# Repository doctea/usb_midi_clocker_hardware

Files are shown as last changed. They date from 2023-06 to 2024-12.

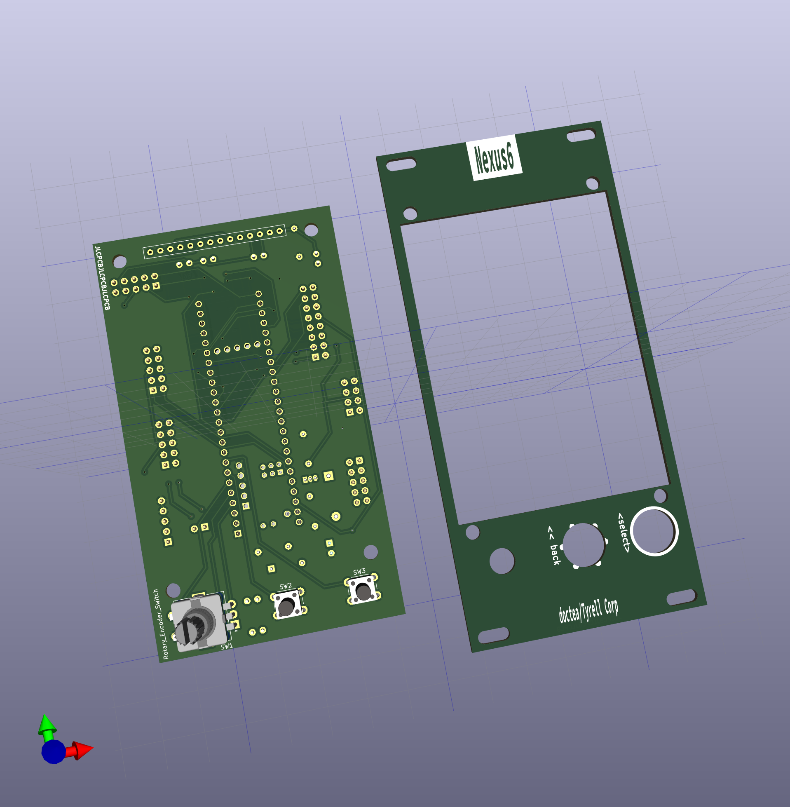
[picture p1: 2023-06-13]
usb_midi_clocker circuits rear.png

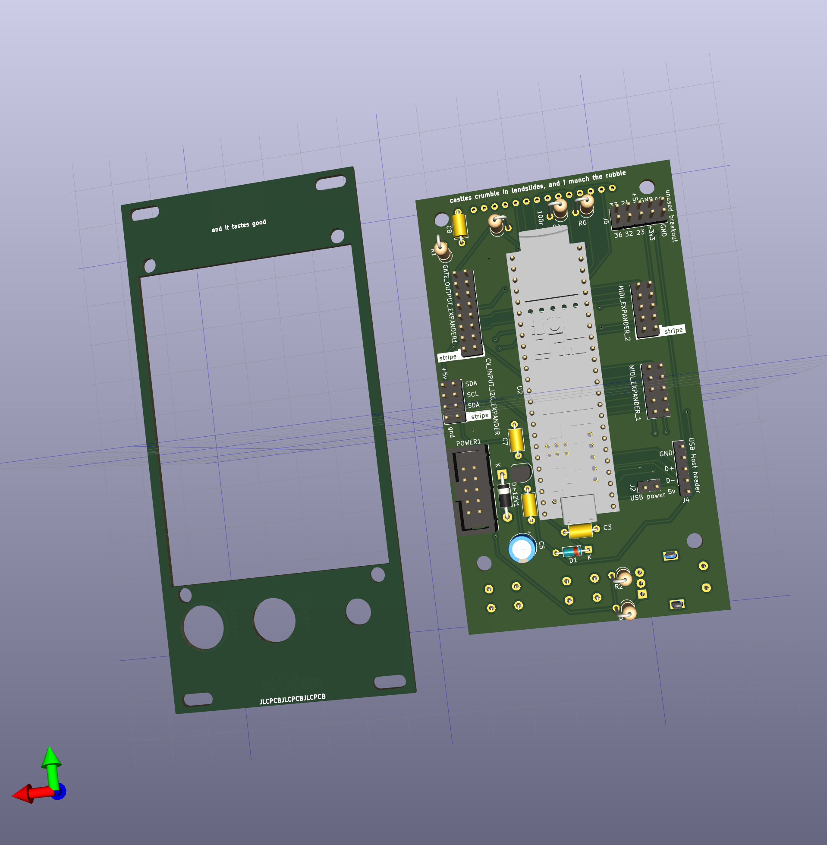
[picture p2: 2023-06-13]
usb_midi_clocker circuits.png

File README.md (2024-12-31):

*IMPORTANT: DO NOT USE THESE FOR ANYTHING YET, THEY ARE VERY MUCH PROTOTYPES AND HAVE SOME PROBLEMS!!!!*

Files for PCB modules for use by [usb_midi_clocker](https://github.com/doctea/usb_midi_clocker/) project.

# Todo

## General

- IMPROVE: reduce size of jack holes to make a snugger fit with less wobble?
- IMPROVE: Some nice panel graphics!

## Main module

### Main module board

- DONE: FIX: Replace the voltage regulator with one that will actually be able to deliver enough amps to power the screen and Teensy *facepalm*
 - ~~Can work around this for the moment by connecting directly to 5v Eurorack power with eg Dupont cables~~
- FIX: Fix/bridge/remove power diode that prevents power from USB going to screen
- IMPROVE: Make the i2c port into a 2x5 connector
- IMPROVE: Add 100ohm resistors on the SPI connectors

### Main module panel

- DONE: IMPROVE: Cutout for display pins in order to allow the panel to sit flat on top of the display without bending like it currently does?
- DONE/UNTESTED: FIX: Make the encoder hole bigger, so that the encoder will fit through

## Gate expander

### Gate expander back board

- FIX: ?? fix whatever the problem is that is making SPI unreliable af and lights randomly seeming to not go off
- DONE/UNTESTED: one of the protection diodes isn't connected to ground
- FIX: eratic behaviour where LEDs stay lit, don't light up properly, etc
	- seems to be fixed/worked around by dropping SPI rate and putting a 22pf cap between MOSI+GND, one between GND+CS1, on between GND+SCK, one between CS1+SCK, and a 100ohm resistor between CS1+SCK too
- FIX: when put into 'inputs' mode, all seem to read HIGH when there isn't anything connected?
- FIX: when put into 'inputs' mode, two of the SEQUENCER channels randomly flicker on/off...?
- FIX: the switch pins currently connect tip to ground; should this go through a large resistor to act as a pull-down?  or not happen at all?
- FIX: layout of the 'sequencer' outputs isn't right, for unknown reasons? (worked around in software)

### Gate expander jacks board

- FIX/UNTESTED: outputs 13+14 had their resistor values accidentally swapped - 1k <-> 47k!

### Gate expander panel

- IMPROVE: make reversible in / out, or label as CLOCK / SEQUENCER

## CV Input expander

### CV Input board

- IMPROVE: make header 2x5 instead of 2x4?

## MIDI expander

- Seems to be working on first attempt!
- IMPROVE: pitch spacing of the resistors/capacitors to allow common components to fit a little better (slightly wider resistor spacing, slightly narrower capacitor spacing)
- IMPROVE: maybe add protection diodes to protect the Teensy's GPIO pins in the event of wrong thing being connected?
- IMPROVE: Make panel double-sided (in+outs 1-4 on one side, 5-6 on the other)
- IMPROVE: probably possible to do this in 3hp instead of 4hp

## USB+SD expander

- TODO: Add a way to directly power USB Host from case's 5V
- TODO: IMPORTANT! Label the USB Host pins so that can tell which end is ground!

## CV Output expander

- DONE: correct the ADC inputs, as they are reversed on the first boards! (A was connected to C and C was connected to A) *facepalm*
- FIX: find correct footprint/component to use for the +12/-12v protection diodes (workaround is to just bridge the connections -- remember to do this BEFORE spending 6 hours debugging everything else!!  Without this, it will look like the DAC chip is working except you won't get any output at all!!!)
- IMPROVE: move the power connector to the inside edge of the board and use right-angle pin headers 
- IMPROVE: use right-angle pin headers/socket for the expander port; maybe get rid of one of the duplicate expander port to give more room for the power connector
- IMPROVE: label the stripe on the expander port(s)

### Addresses

| Address | A1  | A0  | Note |
| --- | --- | --- | ---- |
|  0x4C | LOW | LOW | correct |
|  0x4D | LOW | HIGH | incorrectly seems to stick at 0x4C as if A0 is stuck low? |
|  0x4E | HIGH | LOW | correct |
|  0x4F | HIGH | HIGH | untested - presumed non-working as A0 seems to be stuck low in this hardware revision? |

| Bank | A3 | A2 | Note |
| ---- | -- | -- | ---- |
| 0 | LOW | LOW | Correct |
| 1 | LOW | HIGH | Correct |
| 2 | HIGH | LOW | untested but presumed working |
| 3 | HIGH | HIGH | untested but presumed working |

# Future

- Daughterboards to replace the CV input (currently reliant on Pimoroni 24v ADC module):
 - Own replacement for the Pimoroni board (believe this to be beyond my current ability)
 - Daughterboard to add 3xGate outputs, instead of inputs, based around a GPIO i2c
- Expander-for-the-expander to add switches to select uni-polar/bipolar modes -- with GPIO i2c on there, too, so that we know in software to switch modes and use different calibration data

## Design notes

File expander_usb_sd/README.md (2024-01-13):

#TODO

- DONE check measurements of the USB C screw-holes
- DONE check measurements of cutout for the SD card holder
- DONEish arrange silkscreen text so purpose of each connector is properly usable

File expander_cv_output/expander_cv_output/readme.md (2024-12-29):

https://www.falstad.com/circuit/circuitjs.html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

https://www.falstad.com/circuit/circuitjs.html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

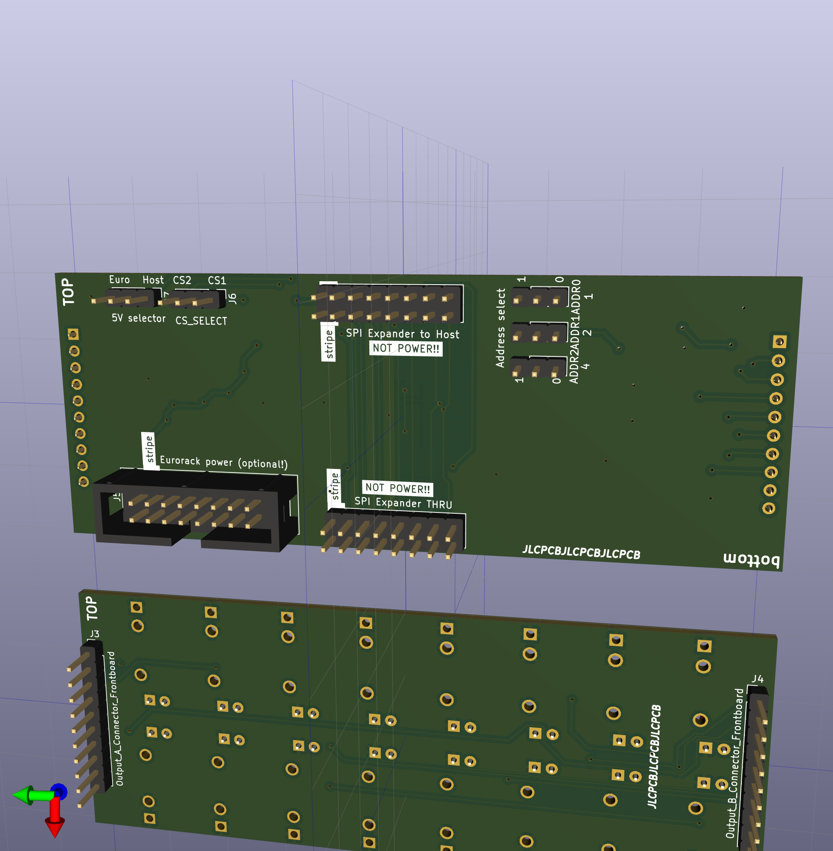
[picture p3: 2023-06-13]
expander_gate_output/expander_gate_output settings.png

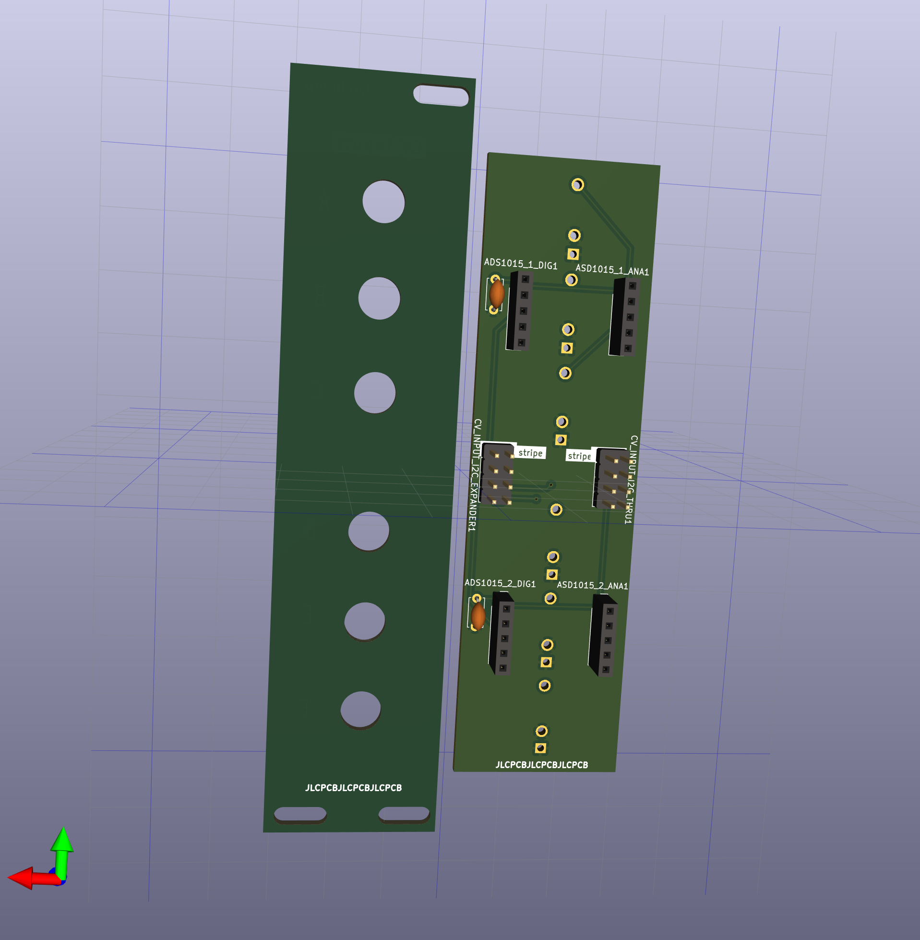
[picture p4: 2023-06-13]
expander_cv_input/expander_cv_input rear.png

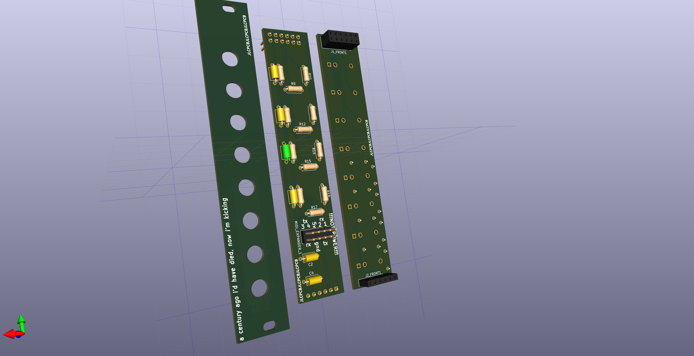
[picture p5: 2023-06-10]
expander_midi/expander_midi.png

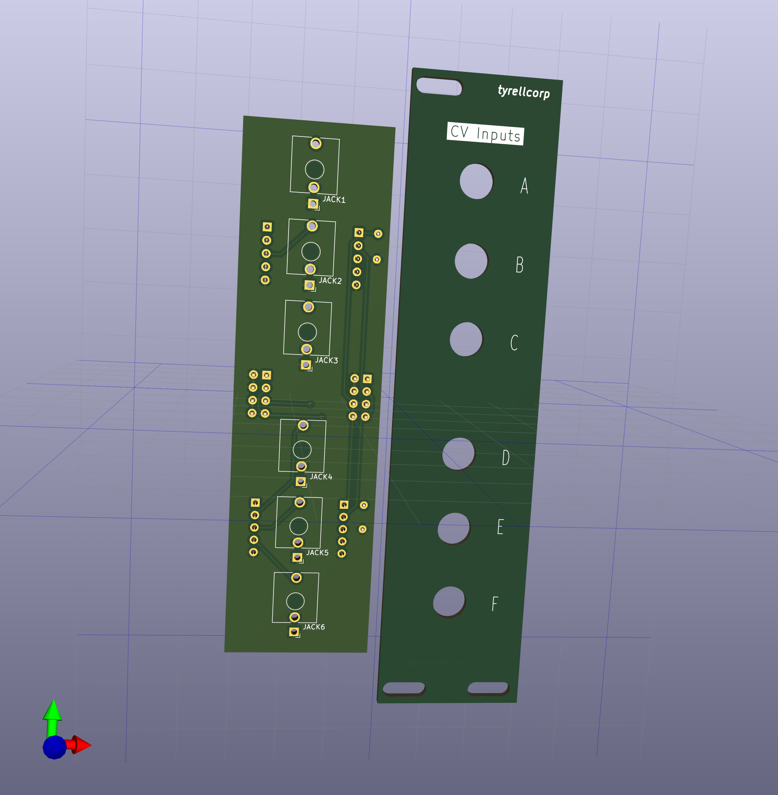
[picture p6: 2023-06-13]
expander_cv_input/expander_cv_input.png

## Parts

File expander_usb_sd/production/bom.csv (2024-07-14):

Designator | Footprint | Quantity | Value | LCSC Part #
External_USB_A_Host1 | ONSHORE_USB-A1VSB6 | 1 | USB_A
H1, H2 | MountingHole_3.2mm_M3 | 2 | MountingHole
J1 | PJS008U-3000-0 | 1 | Micro_SD_Card_Det1
J1-TeensyPower1 | PinHeader_1x02_P2.54mm_Vertical | 1 | USB power - Teensy device
J2 | PinHeader_1x05_P2.54mm_Vertical | 1 | Internal_USB_Host_Teensy
J5-TeensyMicroUSB1 | PinHeader_1x05_P2.54mm_Vertical | 1 | USB 5 pin to Teensy/MicroUSB
J6-USBHost1 | PinHeader_1x05_P2.54mm_Vertical | 1 | USB 5 pin to frontpanel/Type C
SD_connector1 | PinHeader_2x04_P2.54mm_Vertical | 1 | Conn_02x04_Odd_Even
USBHostPower1 | PinHeader_1x02_P2.54mm_Vertical | 1 | USB power - host

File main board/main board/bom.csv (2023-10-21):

Designator | Footprint | Quantity | Value | LCSC Part #
C3, C8 | C_Axial_L5.1mm_D3.1mm_P7.50mm_Horizontal | 2 | C_Small
C5 | CP_Radial_D6.3mm_P2.50mm | 1 | C_Polarized_Small
C6 | C_Axial_L5.1mm_D3.1mm_P7.50mm_Horizontal | 1 | 330nF
C7 | C_Axial_L5.1mm_D3.1mm_P7.50mm_Horizontal | 1 | 100nF
D+12V1 | D_DO-41_SOD81_P10.16mm_Horizontal | 1 | 1N5817
D1 | D_DO-35_SOD27_P7.62mm_Horizontal | 1 | 1N4148
GATE_OUTPUT_EXPANDER1 | PinHeader_2x08_P2.54mm_Vertical | 1 | 16 pin header
I2C_EXPANDER | PinHeader_2x04_P2.54mm_Vertical | 1 | 8 pin header
J2 | PinHeader_1x02_P2.54mm_Vertical | 1 | USB power
J4 | PinHeader_1x05_P2.54mm_Vertical | 1 | USB Host header
J5 | PinHeader_2x05_P2.54mm_Vertical | 1 | Conn_01x09_Pin
MIDI_EXPANDER_1, MIDI_EXPANDER_2 | PinHeader_2x05_P2.54mm_Vertical | 2 | Conn_02x05_Counter_Clockwise
POWER1 | IDC-Header_2x05_P2.54mm_Vertical | 1 | Eurorack power header
R1, R4 | R_Axial_DIN0309_L9.0mm_D3.2mm_P2.54mm_Vertical | 2 | 100R
R2, R3, R5, R6 | R_Axial_DIN0309_L9.0mm_D3.2mm_P2.54mm_Vertical | 4 | R
SW1 | RotaryEncoder_Alps_EC11E-Switch_Vertical_H20mm | 1 | Rotary_Encoder_Switch
SW2 | SW_PUSH_6mm_H13mm | 1 | SW_Push_Back
SW3 | SW_PUSH_6mm_H13mm | 1 | SW_Push_Select
U2 | Teensy41 | 1 | Teensy4.1
U3 | doctea ili9341 3.2 | 1 | TFT_320x240
U4 | TO-220-3_Vertical | 1 | L7805

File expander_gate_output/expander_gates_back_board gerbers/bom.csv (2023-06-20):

Designator | Footprint | Quantity | Value | LCSC Part #
C1, C2, C5, C6, C7 | 0805 | 5 | C_Small
D1, D10, D11, D12, D13, D14, D15, D16, D2, D25, D26, D27, D28, D29, D3, D30, D31, D32, D33, D34, D35, D36, D37, D38, D39, D4, D40, D5, D6, D7, D8, D9 | D_SOD-123 | 32 | BAT43
EXPANDER_THRU, GATE_SPI_OUTPUT_EXPANDER1 | PinHeader_2x08_P2.54mm_Vertical | 2 | 16 pin header
J1 | PinSocket_1x10_P2.54mm_Vertical | 1 | Output_A_Connector_Backboard
J16 | PinHeader_1x03_P2.54mm_Vertical | 1 | ADDR0
J17 | PinHeader_1x03_P2.54mm_Vertical | 1 | ADDR1
J18 | PinHeader_1x03_P2.54mm_Vertical | 1 | ADDR2
J2 | PinSocket_1x10_P2.54mm_Vertical | 1 | Output_B_Connector_Backboard
J5 | IDC-Header_2x08_P2.54mm_Vertical | 1 | Eurorack power
J6 | PinHeader_1x03_P2.54mm_Vertical | 1 | CS_SELECT
J7 | PinHeader_1x03_P2.54mm_Vertical | 1 | 5V selector
U1, U2 | TSSOP-20_4.4x6.5mm_P0.65mm | 2 | TXS0108EPW
U3 | SSOP-28_5.3x10.2mm_P0.65mm | 1 | MCP23S17_SS

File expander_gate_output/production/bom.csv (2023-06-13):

Designator | Footprint | Quantity | Value | LCSC Part #
C1, C2, C5, C6, C7 | 0805 | 5 | C_Small
D1, D10, D11, D12, D13, D14, D15, D16, D2, D25, D26, D27, D28, D29, D3, D30, D31, D32, D33, D34, D35, D36, D37, D38, D39, D4, D40, D5, D6, D7, D8, D9 | 0805 | 32 | BAT43
D17, D18, D19, D20, D21, D22, D23, D24, D41, D42, D43, D44, D45, D46, D47, D48 | LED_D3.0mm | 16 | LED
J1 | PinSocket_1x10_P2.54mm_Vertical | 1 | Output_A_Connector_Backboard
J16 | PinHeader_1x03_P2.54mm_Vertical | 1 | ADDR0
J17 | PinHeader_1x03_P2.54mm_Vertical | 1 | ADDR1
J18 | PinHeader_1x03_P2.54mm_Vertical | 1 | ADDR2
J2 | PinSocket_1x10_P2.54mm_Vertical | 1 | Output_B_Connector_Backboard
J3 | PinHeader_1x10_P2.54mm_Vertical | 1 | Output_A_Connector_Frontboard
J4 | PinHeader_1x10_P2.54mm_Vertical | 1 | Output_B_Connector_Frontboard
J5 | IDC-Header_2x08_P2.54mm_Vertical | 1 | Eurorack power
J6 | PinHeader_1x03_P2.54mm_Vertical | 1 | CS_SELECT
J7 | PinHeader_1x03_P2.54mm_Vertical | 1 | 5V selector
JACK1, JACK14 | Thonkiconn Renumbered | 2 | ~
JACK10, JACK11, JACK12, JACK13, JACK15, JACK16, JACK2, JACK3, JACK4, JACK5, JACK6, JACK7, JACK8, JACK9 | Thonkiconn Renumbered | 14 | fuzzySI_thonkiconn
R1, R11, R13, R15, R17, R19, R21, R23, R25, R27, R29, R3, R31, R5, R7, R9 | 0805 | 16 | 47K
R10, R12, R14, R16, R18, R2, R20, R22, R24, R26, R28, R30, R32, R4, R6, R8 | 0805 | 16 | 1K
SPI Expander THRU | PinHeader_2x08_P2.54mm_Vertical | 1 | NOT POWER!!
SPI Expander to Host | PinHeader_2x08_P2.54mm_Vertical | 1 | 16 pin header
U1, U2 | TSSOP-20_4.4x6.5mm_P0.65mm | 2 | TXS0108EPW
U3 | SSOP-28_5.3x10.2mm_P0.65mm | 1 | MCP23S17_SS

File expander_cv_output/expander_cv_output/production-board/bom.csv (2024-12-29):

Designator | Footprint | Quantity | Value | LCSC Part #
ADDR_A0, ADDR_A1, ADDR_A2, ADDR_A3 | SolderJumper-3_P1.3mm_Open_RoundedPad1.0x1.5mm | 4 | Conn_01x03_Pin
ADS1015_2_DIG1 | PinSocket_1x05_P2.54mm_Vertical | 1 | ADS1015 digital side
ASD1015_2_ANA1 | PinSocket_1x05_P2.54mm_Vertical | 1 | ADS1015 analog side
C1, C12, C13, C16, C17, C18, C19, C2, C5, C6, C7, C9 | 0805 | 12 | 100nF
C10, C11, C14, C15 | 0805 | 4 | 22pF
C3, C4 | CP_Elec_5x5.7 | 2 | C_Polarized_Small
C8 | 0805 | 1 | 10uF
D1 | 0805 | 1 | D
D2 | 0805 | 1 | D_Small
DAC1 | TSSOP-16_4.4x5mm_P0.65mm | 1 | DAC8574IPWG4
EURO_POWER1 | PinHeader_2x08_P2.54mm_Vertical | 1 | Conn_02x08_Odd_Even
J2, J7 | IDC-Header_2x05_P2.54mm_Vertical | 2 | Conn_02x05_Odd_Even
J3 | PinHeader_1x02_P2.54mm_Vertical | 1 | SDA pullup
J4 | PinHeader_1x02_P2.54mm_Vertical | 1 | SCL pullup
J5 | PinHeader_2x08_P2.54mm_Vertical | 1 | Conn_02x08_Counter_Clockwise
JACK_A1, JACK_A2, JACK_B1, JACK_B2, JACK_C1, JACK_C2, JACK_D1 | PJ302M | 7 | PJ302M
LED_A1, LED_B1, LED_C1, LED_D1 | LED_D3.0mm | 4 | LED_Dual_Bidirectional
R1, R5, R6 | 0805 | 3 | 10k
R10, R19, R20, R9 | 0805 | 4 | 2.2k
R11, R12, R21, R22 | 0805 | 4 | 220
R13, R14, R17, R18, R23, R24, R7, R8 | 0805 | 8 | 1K
R15, R16, R25, R26 | 0805 | 4 | 47
R2 | 0805 | 1 | 560
R3, R4 | 0805 | 2 | 150r
U1, U2 | SOIC-14_3.9x8.7mm_P1.27mm | 2 | TL074
U3 | SOT-23_Handsoldering | 1 | LM4040DBZ-5
U4 | SOT-23_Handsoldering | 1 | LD1117S33TR_SOT223
U5 | SOT-23_Handsoldering | 1 | LM4040DBZ-33

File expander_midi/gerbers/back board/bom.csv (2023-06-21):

Designator | Footprint | Quantity | Value | LCSC Part #
C1, C4 | C_Axial_L5.1mm_D3.1mm_P7.50mm_Horizontal | 2 | 100nF
C2, C3, C5, C6 | C_Axial_L5.1mm_D3.1mm_P7.50mm_Horizontal | 4 | 100n
J1_BACK1 | PinHeader_2x06_P2.54mm_Vertical | 1 | Conn_02x06_Odd_Even
J2_BACK1 | PinHeader_1x06_P2.54mm_Vertical | 1 | Conn_01x06_Pin
MIDI_EXPANDER_1 | PinHeader_2x05_P2.54mm_Vertical | 1 | Conn_02x05_Counter_Clockwise
R10, R11, R12, R15, R16, R17, R18, R9 | R_Axial_DIN0207_L6.3mm_D2.5mm_P7.62mm_Horizontal | 8 | 220R
R13, R14, R19, R20 | R_Axial_DIN0207_L6.3mm_D2.5mm_P7.62mm_Horizontal | 4 | 470R
U1 | SOT-223-3_TabPin2 | 1 | LD1117
ULPZWmidi1, ULPZWmidi2, ULPZWmidi3, ULPZWmidi4 | SO-8_3.9x4.9mm_P1.27mm | 4 | HCPL-0631

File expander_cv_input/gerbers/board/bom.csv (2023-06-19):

Designator | Footprint | Quantity | Value | LCSC Part #
ADS1015_1_DIG1, ADS1015_2_DIG1 | PinSocket_1x05_P2.54mm_Vertical | 2 | ADS1015 digital side
ASD1015_1_ANA1, ASD1015_2_ANA1 | PinSocket_1x05_P2.54mm_Vertical | 2 | ADS1015 analog side
C1, C2 | C_Disc_D5.0mm_W2.5mm_P5.00mm | 2 | 100n
CV_INPUT_I2C_EXPANDER1, CV_INPUT_I2C_THRU1 | PinHeader_2x04_P2.54mm_Vertical | 2 | 8 pin header
JACK1, JACK2, JACK3, JACK4, JACK5, JACK6 | Jack_3.5mm_QingPu_WQP-PJ398SM_Vertical_CircularHoles | 6 | AudioJack2_SwitchT

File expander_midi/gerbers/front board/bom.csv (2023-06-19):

Designator | Footprint | Quantity | Value | LCSC Part #
J1_FRONT1 | PinSocket_2x06_P2.54mm_Vertical | 1 | Conn_02x06_Odd_Even
J2_FRONT1 | PinSocket_1x06_P2.54mm_Vertical | 1 | Conn_01x06_Socket
JMIDIIN1, JMIDIIN2, JMIDIIN3, JMIDIIN4, JMIDIOUT1, JMIDIOUT2, JMIDIOUT3, JMIDIOUT4 | Jack_3.5mm_QingPu_WQP-PJ398SM_TRS_Vertical_CircularHoles | 8 | MIDI In Jack 3.5mm stereo jack
R1, R2, R3, R4, R5, R6, R7, R8 | R_Axial_DIN0207_L6.3mm_D2.5mm_P7.62mm_Horizontal | 8 | 47R

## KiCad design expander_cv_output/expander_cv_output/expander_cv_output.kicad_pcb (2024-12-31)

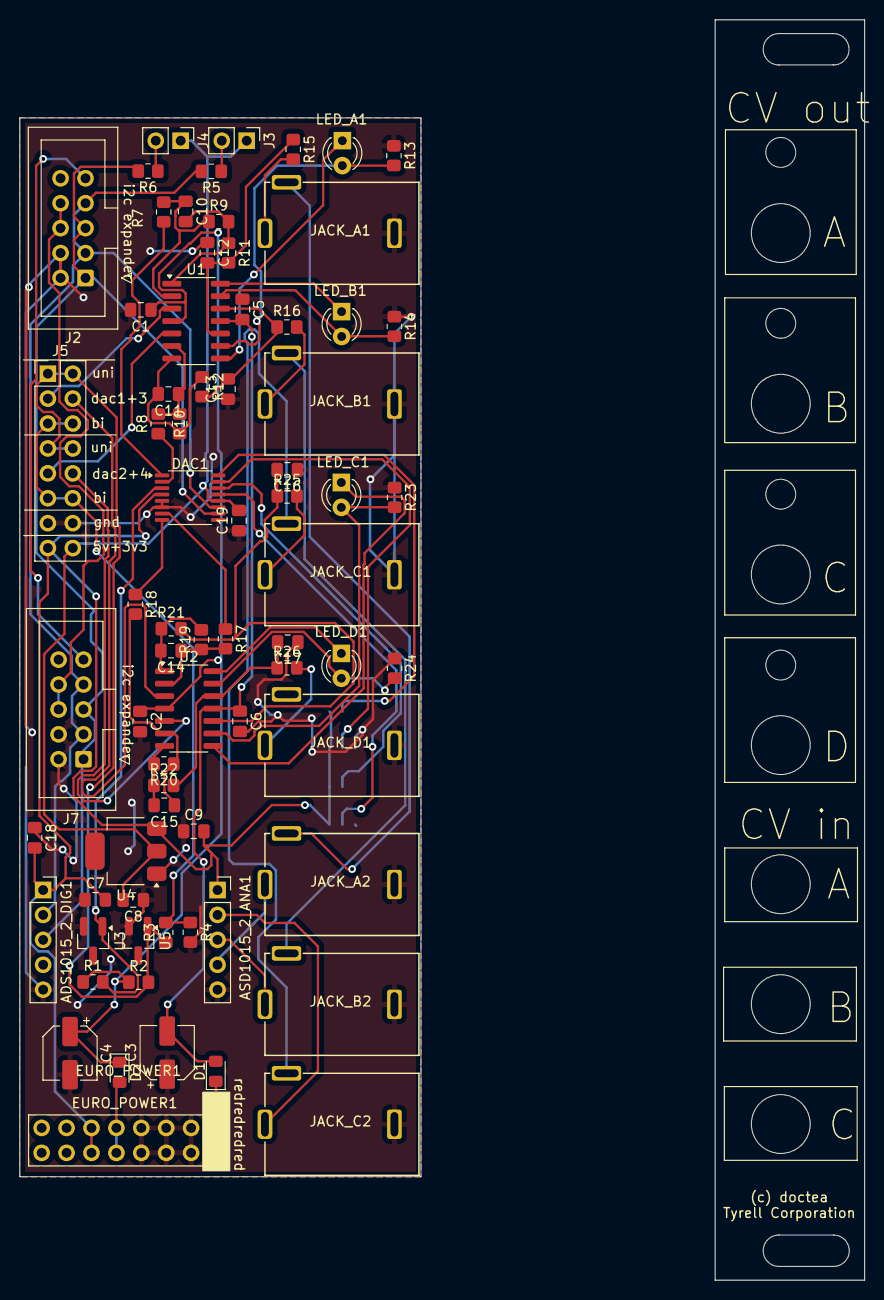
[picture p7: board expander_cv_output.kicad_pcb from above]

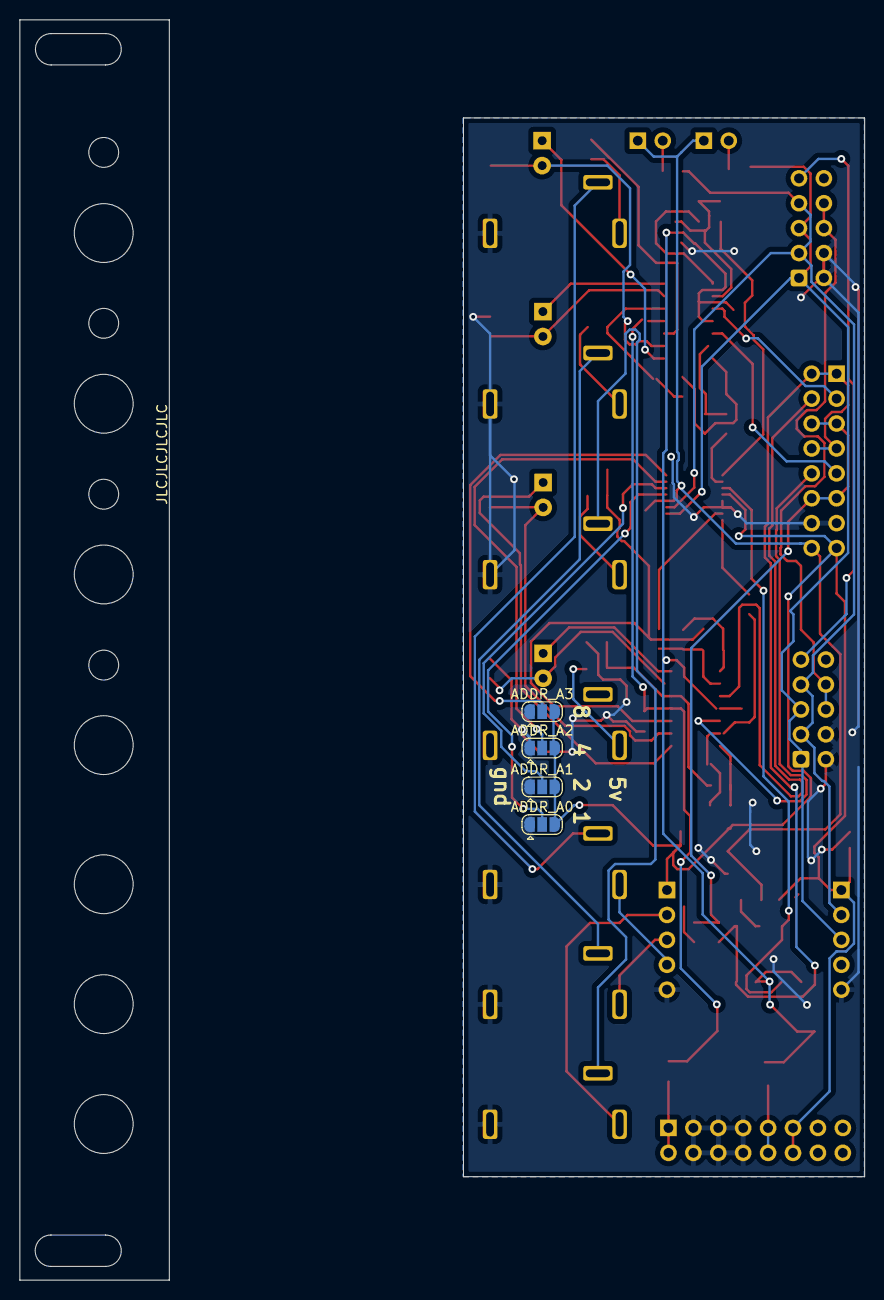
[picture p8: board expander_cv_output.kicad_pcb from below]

Board: 2 copper layers, 40.9 x 108.0 mm, 76 parts (4 on the bottom side), 59 nets.

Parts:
ADDR_A0, ADDR_A1, ADDR_A2, ADDR_A3: Conn_01x03_Pin; SolderJumper-3_P1.3mm_Open_RoundedPad1.0x1.5mm
ADS1015_2_DIG1: ADS1015 digital side; PinSocket_1x05_P2.54mm_Vertical
ASD1015_2_ANA1: ADS1015 analog side; PinSocket_1x05_P2.54mm_Vertical
C1, C2, C5, C6, C7, C9, C12, C13, C16, C17, C18, C19: 100nF; C_0805_2012Metric_Pad1.18x1.45mm_HandSolder
C3, C4: 10uF; CP_Elec_5x5.7
C8: 10uF; C_0805_2012Metric_Pad1.18x1.45mm_HandSolder
C10, C11, C14, C15: 22pF; C_0805_2012Metric_Pad1.18x1.45mm_HandSolder
D1, D2: 1N5817; D_0805_2012Metric_Pad1.15x1.40mm_HandSolder
DAC1: DAC8574IPWG4; TSSOP-16_4.4x5mm_P0.65mm
EURO_POWER1: Conn_02x08_Odd_Even; PinHeader_2x08_P2.54mm_Vertical
J2, J7: Conn_02x05_Odd_Even; IDC-Header_2x05_P2.54mm_Vertical
J3: SDA pullup; PinHeader_1x02_P2.54mm_Vertical
J4: SCL pullup; PinHeader_1x02_P2.54mm_Vertical
J5: Conn_02x08_Counter_Clockwise; PinHeader_2x08_P2.54mm_Vertical
JACK_A1, JACK_A2: PJ302M
JACK_B1, JACK_B2: PJ302M
JACK_C1, JACK_C2: PJ302M
JACK_D1: PJ302M
LED_A1: LED_Dual_Bidirectional; LED_D3.0mm
LED_B1: LED_Dual_Bidirectional; LED_D3.0mm
LED_C1: LED_Dual_Bidirectional; LED_D3.0mm
LED_D1: LED_Dual_Bidirectional; LED_D3.0mm
R1, R5, R6: 10k; R_0805_2012Metric_Pad1.20x1.40mm_HandSolder
R2: 560; R_0805_2012Metric_Pad1.20x1.40mm_HandSolder
R3, R4: 150r; R_0805_2012Metric_Pad1.20x1.40mm_HandSolder
R7, R8, R13, R14, R17, R18, R23, R24: 1K; R_0805_2012Metric_Pad1.20x1.40mm_HandSolder
R9, R10, R19, R20: 2.2k; R_0805_2012Metric_Pad1.20x1.40mm_HandSolder
R11, R12, R21, R22: 220; R_0805_2012Metric_Pad1.20x1.40mm_HandSolder
R15, R16, R25, R26: 47; R_0805_2012Metric_Pad1.20x1.40mm_HandSolder
U1, U2: TL074; SOIC-14_3.9x8.7mm_P1.27mm
U3: LM4040DBZ-5; SOT-23_Handsoldering
U4: LD1117S33TR_SOT223; SOT-223
U5: LM4040DBZ-33; SOT-23_Handsoldering

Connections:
1.65v reference: J5.5, J5.6, J5.11, J5.12, R3.2, R4.1
3.3V: C8.2, C19.2, DAC1.12 (IOVDD), J3.1, J4.1, J5.16, U4.2 (VO)
3.3v reference: J5.1, J5.2, J5.7, J5.8, R2.2, R3.1, U5.1 (K)
5V: ADDR_A0.3, ADDR_A1.3, ADDR_A2.3, ADDR_A3.3, ADS1015_2_DIG1.1, ASD1015_2_ANA1.1, C7.2, C9.2, C18.2, DAC1.4 (VDD), EURO_POWER1.11, EURO_POWER1.12, J5.15, U4.3 (VI)
5v reference: DAC1.3 (VREFH), R1.2, U3.1 (K)
12V: C1.1, C2.1, C4.1, D2.1 (K), R1.1, R2.1, U1.4 (V+), U2.4 (V+)
+5V from Host: J2.6, J2.8, J7.6, J7.8
-12V: C3.2, C5.2, C6.1, D1.2 (A), U1.11 (V-), U2.11 (V-)
CV GND: ADDR_A0.1, ADDR_A1.1, ADDR_A2.1, ADDR_A3.1, ADS1015_2_DIG1.5, ASD1015_2_ANA1.5, C1.2, C2.2, C3.1, C4.2, C5.1, C6.2, C7.1, C8.1, C9.1, C12.1, C13.1, C16.1, C17.1, C18.1, C19.1, DAC1.5 (VREFL), DAC1.6 (GND), DAC1.9 (LDAC), EURO_POWER1.3, EURO_POWER1.4, EURO_POWER1.5, EURO_POWER1.6, EURO_POWER1.7, EURO_POWER1.8, J2.2, J2.4, J5.13, J5.14, J7.2, J7.4, JACK_A1.1, JACK_A2.1, JACK_B1.1, JACK_B2.1, JACK_C1.1, JACK_C2.1, JACK_D1.1, R4.2, R13.1, R14.1, R23.1, R24.1, U3.2 (A), U4.1 (GND), U5.2 (A)
DAC 1 Bias: J5.3, U1.3 (+)
DAC 2 Bias: J5.9, U1.5 (+)
DAC 3 Bias: J5.4, U2.3 (+)
DAC 4 Bias: J5.10, U2.5 (+)
DAC output 1: DAC1.1 (VOUTA), R7.1
DAC output 2: DAC1.2 (VOUTB), R8.1
DAC output 3: DAC1.7 (VOUTC), R17.1
DAC output 4: DAC1.8 (VOUTD), R18.1
Input Frontboard A: ASD1015_2_ANA1.4, JACK_A2.3
Input Frontboard B: ASD1015_2_ANA1.3, JACK_B2.3
Input Frontboard C: ASD1015_2_ANA1.2, JACK_C2.3
unnamed: ADDR_A0.2, DAC1.13 (A0)
unnamed: ADDR_A1.2, DAC1.14 (A1)
unnamed: ADDR_A2.2, DAC1.15 (A2)
unnamed: ADDR_A3.2, DAC1.16 (A3)
unnamed: C10.2, R9.2, R11.1, U1.1
unnamed: C11.2, R10.2, R12.1, U1.7
unnamed: C14.2, R19.2, R21.1, U2.1
unnamed: C15.2, R20.2, R22.1, U2.7
unnamed: D1.1 (K), EURO_POWER1.1, EURO_POWER1.2
unnamed: D2.2 (A), EURO_POWER1.9, EURO_POWER1.10
unnamed: J2.9, J7.9
unnamed: J2.10, J7.10
unnamed: J3.2, R5.1
unnamed: J4.2, R6.1
unnamed: C10.1, R7.2, R9.1, U1.2 (-)
unnamed: C11.1, R8.2, R10.1, U1.6 (-)
unnamed: C12.2, R11.2, R15.1, U1.10 (+)
unnamed: C13.2, R12.2, R16.1, U1.12 (+)
unnamed: C14.1, R17.2, R19.1, U2.2 (-)
unnamed: C15.1, R18.2, R20.1, U2.6 (-)
unnamed: C16.2, R21.2, R25.1, U2.10 (+)
unnamed: C17.2, R22.2, R26.1, U2.12 (+)
Normal A: JACK_A1.2, JACK_A2.2
Normal B: JACK_B1.2, JACK_B2.2
Normal C: JACK_C1.2, JACK_C2.2
Out A LED Backboard: LED_A1.1 (KA), U1.8
Out A LED Return Backboard: LED_A1.2 (AK), R13.2, U1.9 (-)
Out B LED Backboard: LED_B1.1 (KA), U1.14
Out B LED Return Backboard: LED_B1.2 (AK), R14.2, U1.13 (-)
Out C LED Backboard: LED_C1.1 (KA), U2.8
Out C LED Return Backboard: LED_C1.2 (AK), R23.2, U2.9 (-)
Out D LED Backboard: LED_D1.1 (KA), U2.14
Out D LED Return Backboard: LED_D1.2 (AK), R24.2, U2.13 (-)
Output Backboard A: JACK_A1.3, R15.2
Output Backboard B: JACK_B1.3, R16.2
Output Backboard C: JACK_C1.3, R25.2
Output Backboard D: JACK_D1.3, R26.2
i2c SCL: ADS1015_2_DIG1.3, DAC1.10 (SCL), J2.1, J2.5, J7.1, J7.5, R6.2
i2c SDA: ADS1015_2_DIG1.2, DAC1.11 (SDA), J2.3, J2.7, J7.3, J7.7, R5.2

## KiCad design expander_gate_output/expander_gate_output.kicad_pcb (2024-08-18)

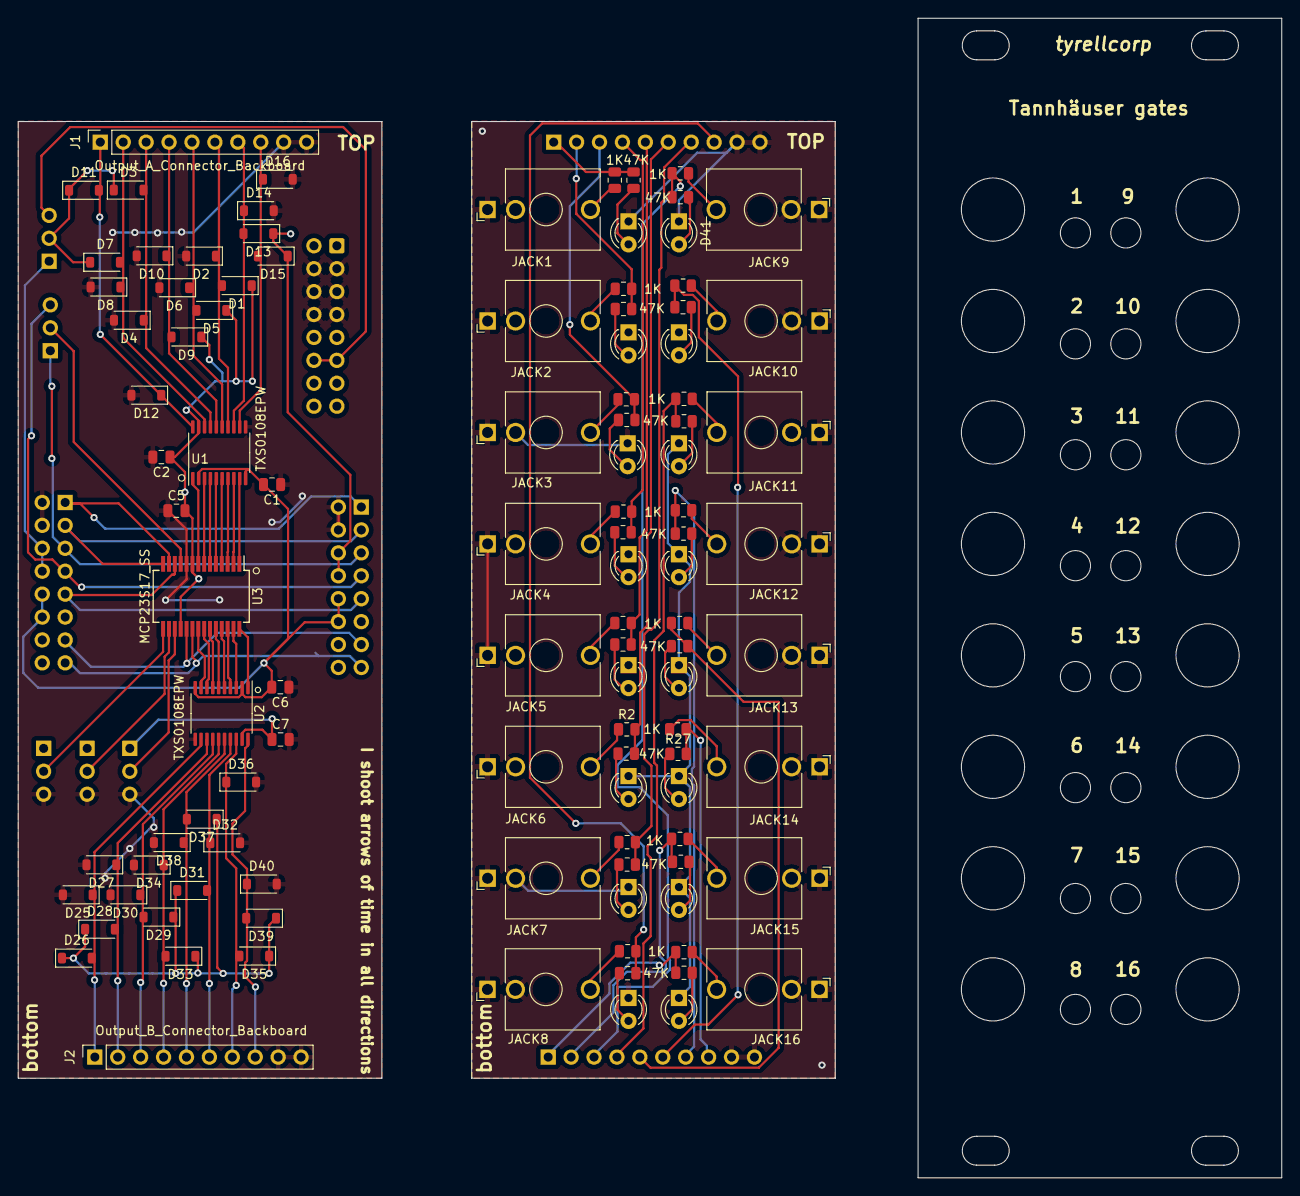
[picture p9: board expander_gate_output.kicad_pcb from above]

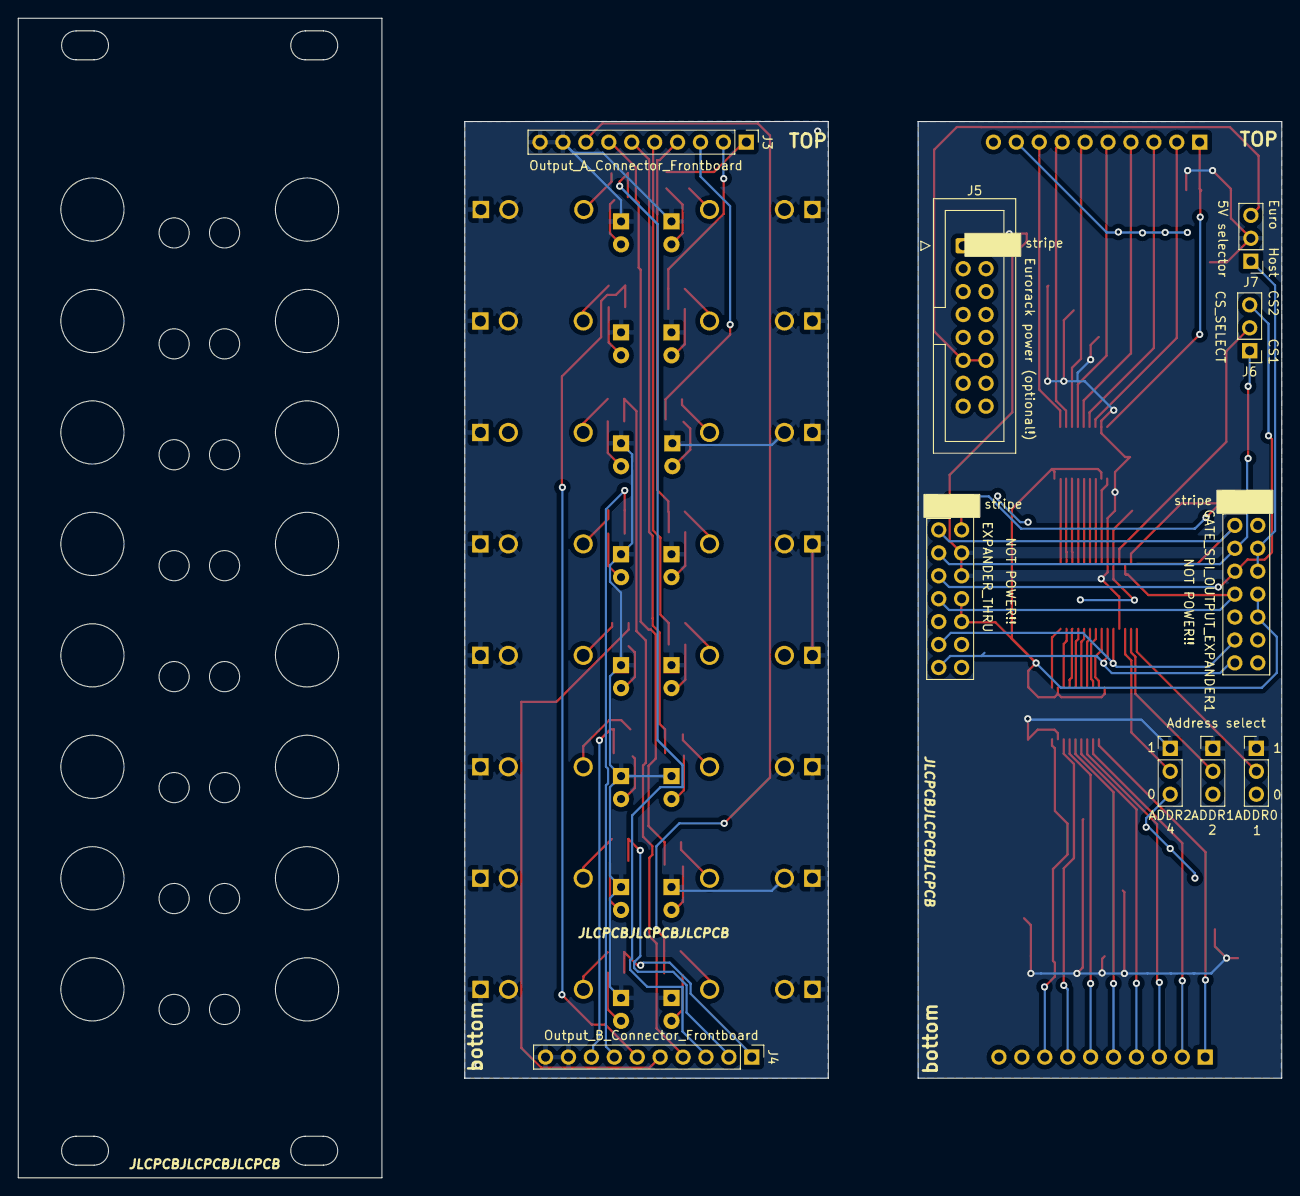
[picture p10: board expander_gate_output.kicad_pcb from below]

Board: 2 copper layers, 140.0 x 128.5 mm, 116 parts (10 on the bottom side), 96 nets.

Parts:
C1, C2, C5, C6, C7: C_Small; C_0805_2012Metric
D1, D2, D3, D4, D5, D6, D7, D8, D9, D10, D11, D12, D13, D14, D15, D16, D25, D26, D27, D28, D29, D30, D31, D32, D33, D34, D35, D36, D37, D38, D39, D40: BAT43; D_SOD-123
D17, D18, D19, D20, D21, D22, D23, D24, D41, D42, D43, D44, D45, D46, D47, D48: LED; LED_D3.0mm
EXPANDER_THRU: 16 pin header; PinHeader_2x08_P2.54mm_Vertical
GATE_SPI_OUTPUT_EXPANDER1: 16 pin header; PinHeader_2x08_P2.54mm_Vertical
J1: Output_A_Connector_Backboard; PinSocket_1x10_P2.54mm_Vertical
J2: Output_B_Connector_Backboard; PinSocket_1x10_P2.54mm_Vertical
J3: Output_A_Connector_Frontboard; PinHeader_1x10_P2.54mm_Vertical
J4: Output_B_Connector_Frontboard; PinHeader_1x10_P2.54mm_Vertical
J5: Eurorack power; IDC-Header_2x08_P2.54mm_Vertical
J6: CS_SELECT; PinHeader_1x03_P2.54mm_Vertical
J7: 5V selector; PinHeader_1x03_P2.54mm_Vertical
J16: ADDR0; PinHeader_1x03_P2.54mm_Vertical
J17: ADDR1; PinHeader_1x03_P2.54mm_Vertical
J18: ADDR2; PinHeader_1x03_P2.54mm_Vertical
JACK1, JACK14: Thonkiconn Renumbered
JACK2, JACK3, JACK4, JACK5, JACK6, JACK7, JACK8, JACK9, JACK10, JACK11, JACK12, JACK13, JACK15, JACK16: fuzzySI_thonkiconn; Thonkiconn Renumbered
R1, R3, R5, R7, R9, R11, R13, R15, R17, R19, R21, R23, R25, R27, R29, R31: 47K; R_0805_2012Metric
R2, R4, R6, R8, R10, R12, R14, R16, R18, R20, R22, R24, R26, R28, R30, R32: 1K; R_0805_2012Metric
U1, U2: TXS0108EPW; TSSOP-20_4.4x6.5mm_P0.65mm
U3: MCP23S17_SS; SSOP-28_5.3x10.2mm_P0.65mm

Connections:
+3V3: C1.2, C6.2, EXPANDER_THRU.10, EXPANDER_THRU.12, GATE_SPI_OUTPUT_EXPANDER1.10, GATE_SPI_OUTPUT_EXPANDER1.12, U1.2 (VCCA), U1.10 (OE), U2.2 (VCCA), U2.10 (OE)
+5V: C2.1, C5.2, C7.1, D1.1 (K), D3.1 (K), D5.1 (K), D7.1 (K), D9.1 (K), D11.1 (K), D13.1 (K), D15.1 (K), D26.1 (K), D28.1 (K), D29.1 (K), D31.1 (K), D33.1 (K), D35.1 (K), D37.1 (K), D39.1 (K), EXPANDER_THRU.6, EXPANDER_THRU.8, J7.2, J16.1, J17.1, J18.1, U1.19 (VCCB), U2.19 (VCCB), U3.9 (VDD), U3.18 (~RESET)
+5V from Eurorack: J5.11, J5.12, J7.3
+5V from main: GATE_SPI_OUTPUT_EXPANDER1.6, GATE_SPI_OUTPUT_EXPANDER1.8, J7.1
A0: J16.2, U3.15 (A0)
A1: J17.2, U3.16 (A1)
A2: J18.2, U3.17 (A2)
CS_1: EXPANDER_THRU.5, GATE_SPI_OUTPUT_EXPANDER1.5, J6.1
CS_2: EXPANDER_THRU.7, GATE_SPI_OUTPUT_EXPANDER1.7, J6.3
CS_INPUT: J6.2, U3.11 (~CS)
GATE_1: U1.9 (A8), U3.1 (GPB0)
GATE_2: U1.8 (A7), U3.2 (GPB1)
GATE_3: U1.7 (A6), U3.3 (GPB2)
GATE_4: U1.6 (A5), U3.4 (GPB3)
GATE_5: U1.5 (A4), U3.5 (GPB4)
GATE_6: U1.4 (A3), U3.6 (GPB5)
GATE_7: U1.3 (A2), U3.7 (GPB6)
GATE_8: U1.1 (A1), U3.8 (GPB7)
GATE_9: U2.9 (A8), U3.21 (GPA0)
GATE_10: U2.8 (A7), U3.22 (GPA1)
GATE_11: U2.7 (A6), U3.23 (GPA2)
GATE_12: U2.6 (A5), U3.24 (GPA3)
GATE_13: U2.5 (A4), U3.25 (GPA4)
GATE_14: U2.4 (A3), U3.26 (GPA5)
GATE_15: U2.3 (A2), U3.27 (GPA6)
GATE_16: U2.1 (A1), U3.28 (GPA7)
GND: C1.1, C2.2, C5.1, C6.1, C7.2, D2.2 (A), D4.2 (A), D6.2 (A), D8.2 (A), D10.2 (A), D12.2 (A), D14.2 (A), D16.2 (A), D17.1 (K), D18.1 (K), D19.1 (K), D20.1 (K), D21.1 (K), D22.1 (K), D23.1 (K), D24.1 (K), D25.2 (A), D27.2 (A), D30.2 (A), D32.2 (A), D34.2 (A), D36.2 (A), D38.2 (A), D40.2 (A), D41.1 (K), D42.1 (K), D43.1 (K), D44.1 (K), D45.1 (K), D46.1 (K), D47.1 (K), D48.1 (K), EXPANDER_THRU.2, EXPANDER_THRU.4, GATE_SPI_OUTPUT_EXPANDER1.2, GATE_SPI_OUTPUT_EXPANDER1.4, J1.9, J1.10, J2.9, J2.10, J3.9, J3.10, J4.9, J4.10, J5.3, J5.4, J5.5, J5.6, J5.7, J5.8, J16.3, J17.3, J18.3, JACK1.1, JACK1.2, JACK2.1, JACK2.2, JACK3.1, JACK3.2, JACK4.1, JACK4.2, JACK5.1, JACK6.1, JACK6.2, JACK7.1, JACK7.2, JACK8.1, JACK8.2, JACK9.1, JACK9.2, JACK10.1, JACK10.2, JACK11.1, JACK12.1, JACK12.2, JACK13.1, JACK13.2, JACK14.1, JACK14.2, JACK15.1, JACK15.2, JACK16.1, JACK16.2, U1.11 (GND), U2.11 (GND), U3.10 (VSS)
INT_1: EXPANDER_THRU.15, GATE_SPI_OUTPUT_EXPANDER1.15, U3.20 (INTA)
INT_2: EXPANDER_THRU.13, GATE_SPI_OUTPUT_EXPANDER1.13, U3.19 (INTB)
MISO: EXPANDER_THRU.3, GATE_SPI_OUTPUT_EXPANDER1.3, U3.14 (SO)
MOSI: EXPANDER_THRU.1, GATE_SPI_OUTPUT_EXPANDER1.1, U3.13 (SI)
unnamed: D17.2 (A), R1.1
unnamed: D18.2 (A), R3.1
unnamed: D19.2 (A), R5.1
unnamed: D20.2 (A), R7.1
unnamed: D21.2 (A), R9.1
unnamed: D22.2 (A), R11.1
unnamed: D23.2 (A), R13.1
unnamed: D24.2 (A), R15.1
unnamed: D41.2 (A), R17.1
unnamed: D42.2 (A), R19.1
unnamed: D43.2 (A), R21.1
unnamed: D44.2 (A), R23.1
unnamed: D45.2 (A), R25.1
unnamed: D46.2 (A), R27.1
unnamed: D47.2 (A), R29.1
unnamed: D48.2 (A), R31.1
unnamed: JACK1.3, R12.1
unnamed: JACK2.3, R8.1
unnamed: JACK3.3, R4.1
unnamed: JACK4.3, R10.1
unnamed: JACK5.3, R6.1
unnamed: JACK6.3, R2.1
unnamed: JACK7.3, R14.1
unnamed: JACK8.3, R16.1
unnamed: JACK9.3, R18.1
unnamed: JACK10.3, R20.1
unnamed: JACK11.3, R22.1
unnamed: JACK12.3, R24.1
unnamed: JACK13.3, R26.1
unnamed: JACK14.3, R28.1
unnamed: JACK15.3, R30.1
unnamed: JACK16.3, R32.1
SCK: EXPANDER_THRU.9, GATE_SPI_OUTPUT_EXPANDER1.9, U3.12 (SCK)
output_1_backboard: D11.2 (A), D12.1 (K), J1.1, U1.20 (B1)
output_1_frontboard: J3.1, R11.2, R12.2
output_2_backboard: D7.2 (A), D8.1 (K), J1.2, U1.18 (B2)
output_2_frontboard: J3.2, R7.2, R8.2
output_3_backboard: D3.2 (A), D4.1 (K), J1.3, U1.17 (B3)
output_3_frontboard: J3.3, R3.2, R4.2
output_4_backboard: D9.2 (A), D10.1 (K), J1.4, U1.16 (B4)
output_4_frontboard: J3.4, R9.2, R10.2
output_5_backboard: D5.2 (A), D6.1 (K), J1.5, U1.15 (B5)
output_5_frontboard: J3.5, R5.2, R6.2
output_6_backboard: D1.2 (A), D2.1 (K), J1.6, U1.14 (B6)
output_6_frontboard: J3.6, R1.2, R2.2
output_7_backboard: D13.2 (A), D14.1 (K), J1.7, U1.13 (B7)
output_7_frontboard: J3.7, R13.2, R14.2
output_8_backboard: D15.2 (A), D16.1 (K), J1.8, U1.12 (B8)
output_8_frontboard: J3.8, R15.2, R16.2
output_9_backboard: D39.2 (A), D40.1 (K), J2.8, U2.20 (B1)
output_9_frontboard: J4.8, R27.2, R28.2
output_10_backboard: D35.2 (A), D36.1 (K), J2.7, U2.18 (B2)
output_10_frontboard: J4.7, R23.2, R24.2
output_11_backboard: D31.2 (A), D32.1 (K), J2.6, U2.17 (B3)
output_11_frontboard: J4.6, R19.2, R20.2
output_12_backboard: D37.2 (A), D38.1 (K), J2.5, U2.16 (B4)
output_12_frontboard: J4.5, R25.2, R26.2
output_13_backboard: D33.2 (A), D34.1 (K), J2.4, U2.15 (B5)
output_13_frontboard: J4.4, R21.2, R22.2
output_14_backboard: D29.2 (A), D30.1 (K), J2.3, U2.14 (B6)
output_14_frontboard: J4.3, R17.2, R18.2
output_15_backboard: D27.1 (K), D28.2 (A), J2.2, U2.13 (B7)
output_15_frontboard: J4.2, R29.2, R30.2
output_16_backboard: D25.1 (K), D26.2 (A), J2.1, U2.12 (B8)
output_16_frontboard: J4.1, R31.2, R32.2

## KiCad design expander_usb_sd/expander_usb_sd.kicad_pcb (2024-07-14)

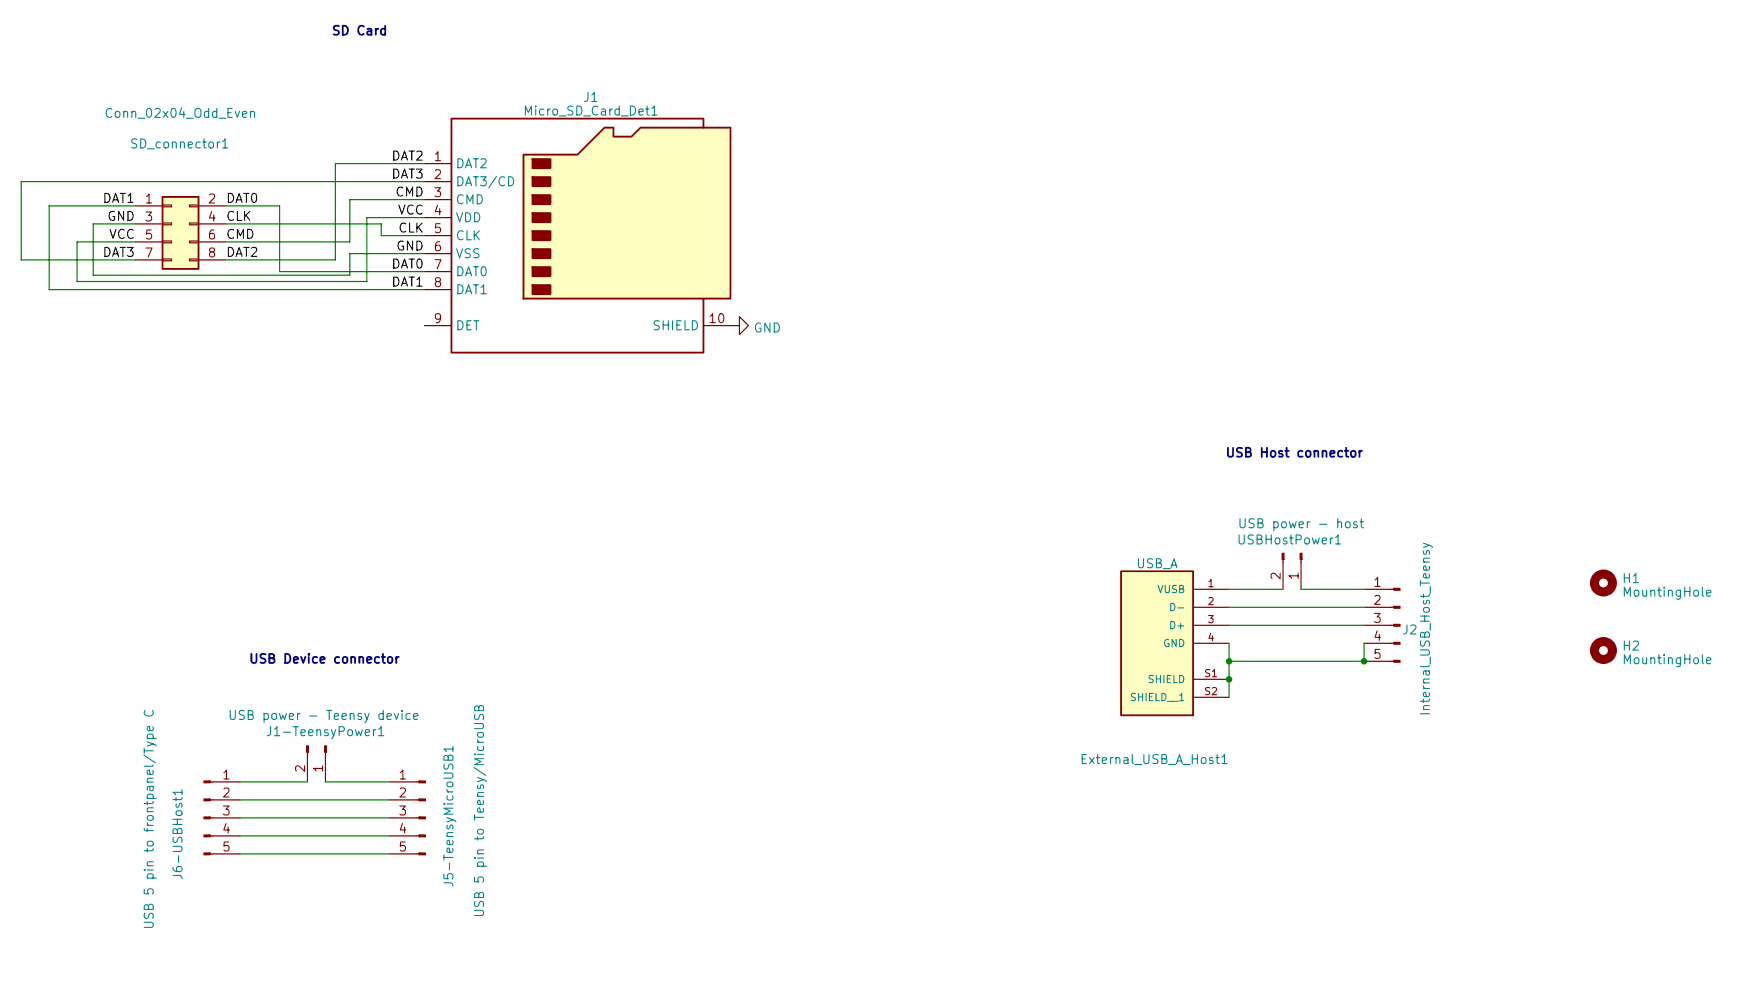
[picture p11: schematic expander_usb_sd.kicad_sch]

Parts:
External_USB_A_Host1: USB_A; ONSHORE_USB-A1VSB6; PARTREV D
H1, H2: MountingHole; MountingHole_3.2mm_M3
J1: Micro_SD_Card_Det1; PJS008U-3000-0
J1-TeensyPower1: USB power - Teensy device; PinHeader_1x02_P2.54mm_Vertical
J2: Internal_USB_Host_Teensy; PinHeader_1x05_P2.54mm_Vertical
J5-TeensyMicroUSB1: USB 5 pin to Teensy/MicroUSB; PinHeader_1x05_P2.54mm_Vertical
J6-USBHost1: USB 5 pin to frontpanel/Type C; PinHeader_1x05_P2.54mm_Vertical
SD_connector1: Conn_02x04_Odd_Even; PinHeader_2x04_P2.54mm_Vertical
USBHostPower1: USB power - host; PinHeader_1x02_P2.54mm_Vertical

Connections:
/CLK: J1.5 (CLK), SD_connector1.4
/CMD: J1.3 (CMD), SD_connector1.6
/DAT0: J1.7 (DAT0), SD_connector1.2
/DAT1: J1.8 (DAT1), SD_connector1.1
/DAT2: J1.1 (DAT2), SD_connector1.8
/DAT3: J1.2 (DAT3/CD), SD_connector1.7
/VCC: J1.4 (VDD), SD_connector1.5
GND: J1.6 (VSS), J1.10 (SHIELD), SD_connector1.3
unnamed: External_USB_A_Host1.3 (D+), J2.3
unnamed: External_USB_A_Host1.2 (D-), J2.2
unnamed: External_USB_A_Host1.4 (GND), External_USB_A_Host1.S1 (SHIELD), External_USB_A_Host1.S2 (SHIELD__1), J2.4, J2.5
unnamed: External_USB_A_Host1.1 (VBUS), USBHostPower1.2
unnamed: J1-TeensyPower1.1, J5-TeensyMicroUSB1.1
unnamed: J1-TeensyPower1.2, J6-USBHost1.1
unnamed: J2.1, USBHostPower1.1
unnamed: J5-TeensyMicroUSB1.2, J6-USBHost1.2
unnamed: J5-TeensyMicroUSB1.3, J6-USBHost1.3
unnamed: J5-TeensyMicroUSB1.4, J6-USBHost1.4
unnamed: J5-TeensyMicroUSB1.5, J6-USBHost1.5

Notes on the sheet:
USB Host connector
SD Card
USB Device connector

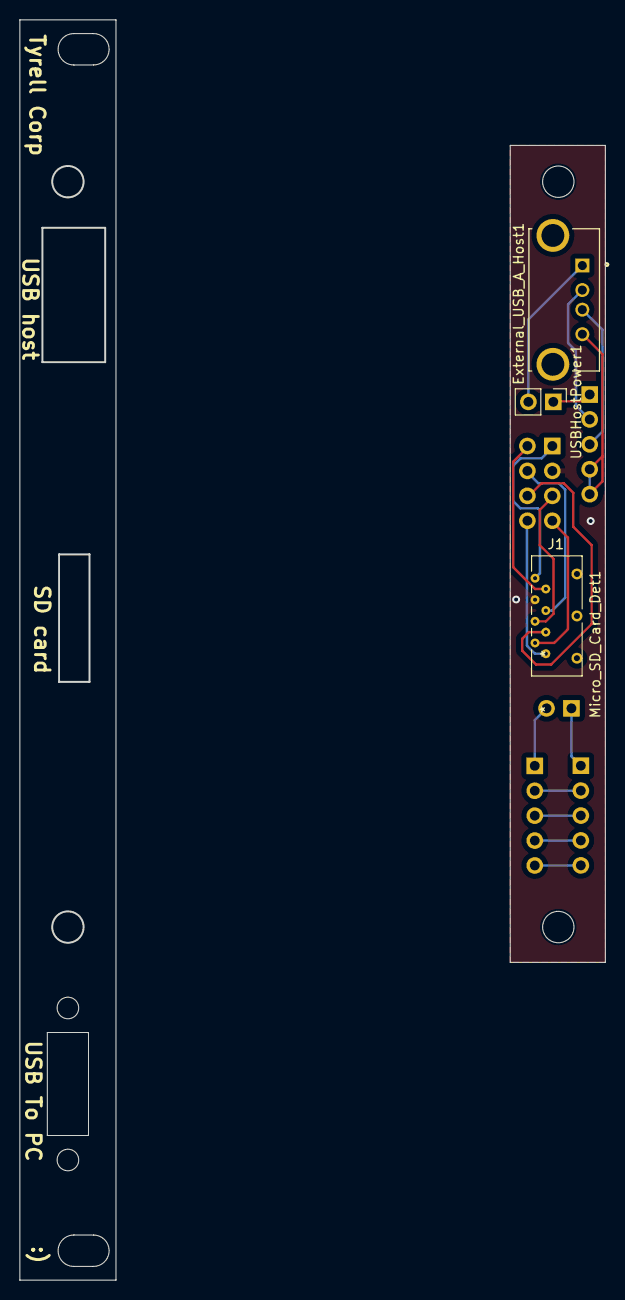
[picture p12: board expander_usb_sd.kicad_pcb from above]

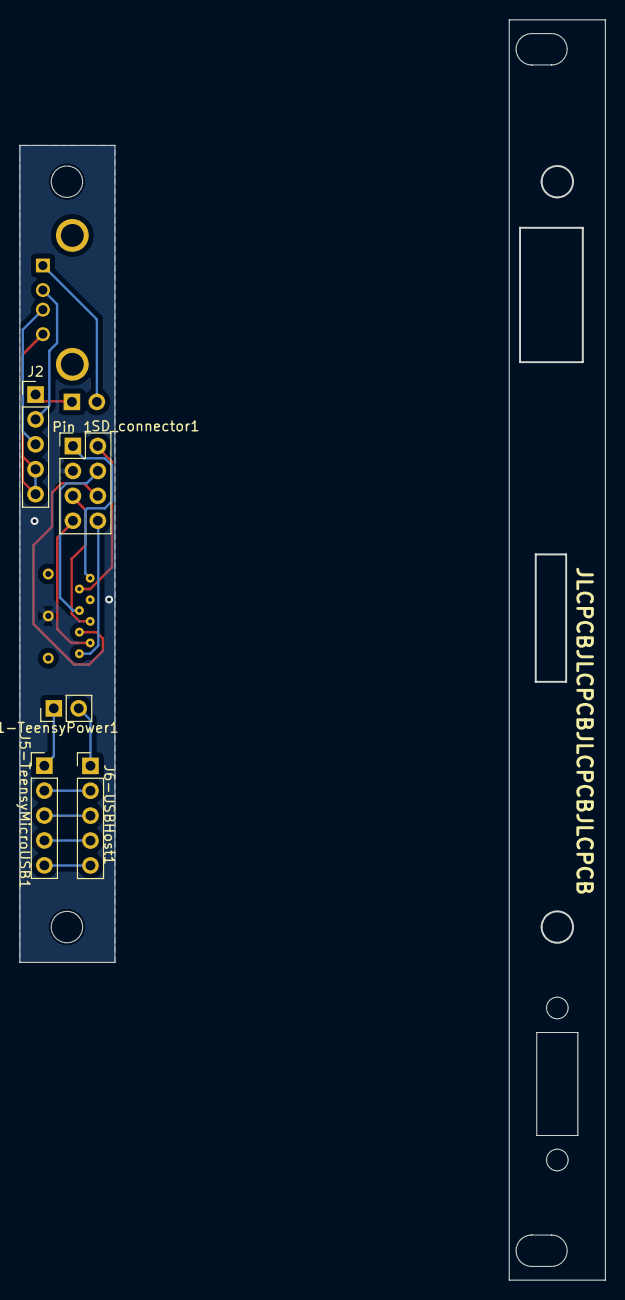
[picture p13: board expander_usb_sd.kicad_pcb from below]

Board: 2 copper layers, 9.7 x 83.3 mm, 10 parts (5 on the bottom side), 19 nets.

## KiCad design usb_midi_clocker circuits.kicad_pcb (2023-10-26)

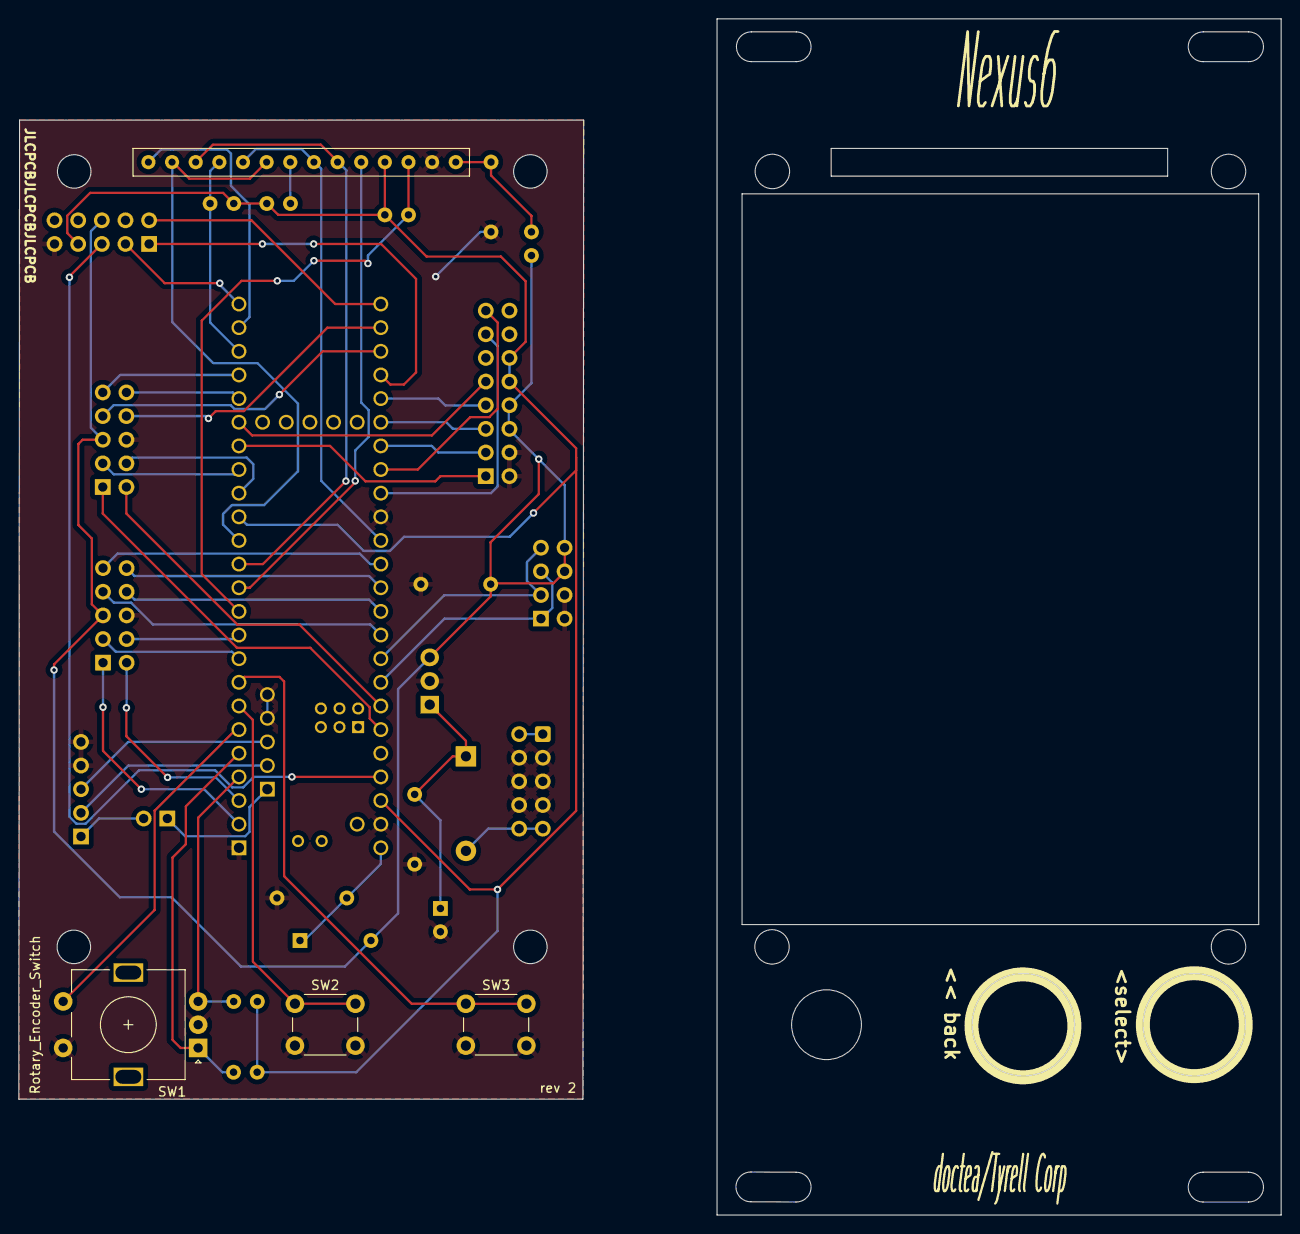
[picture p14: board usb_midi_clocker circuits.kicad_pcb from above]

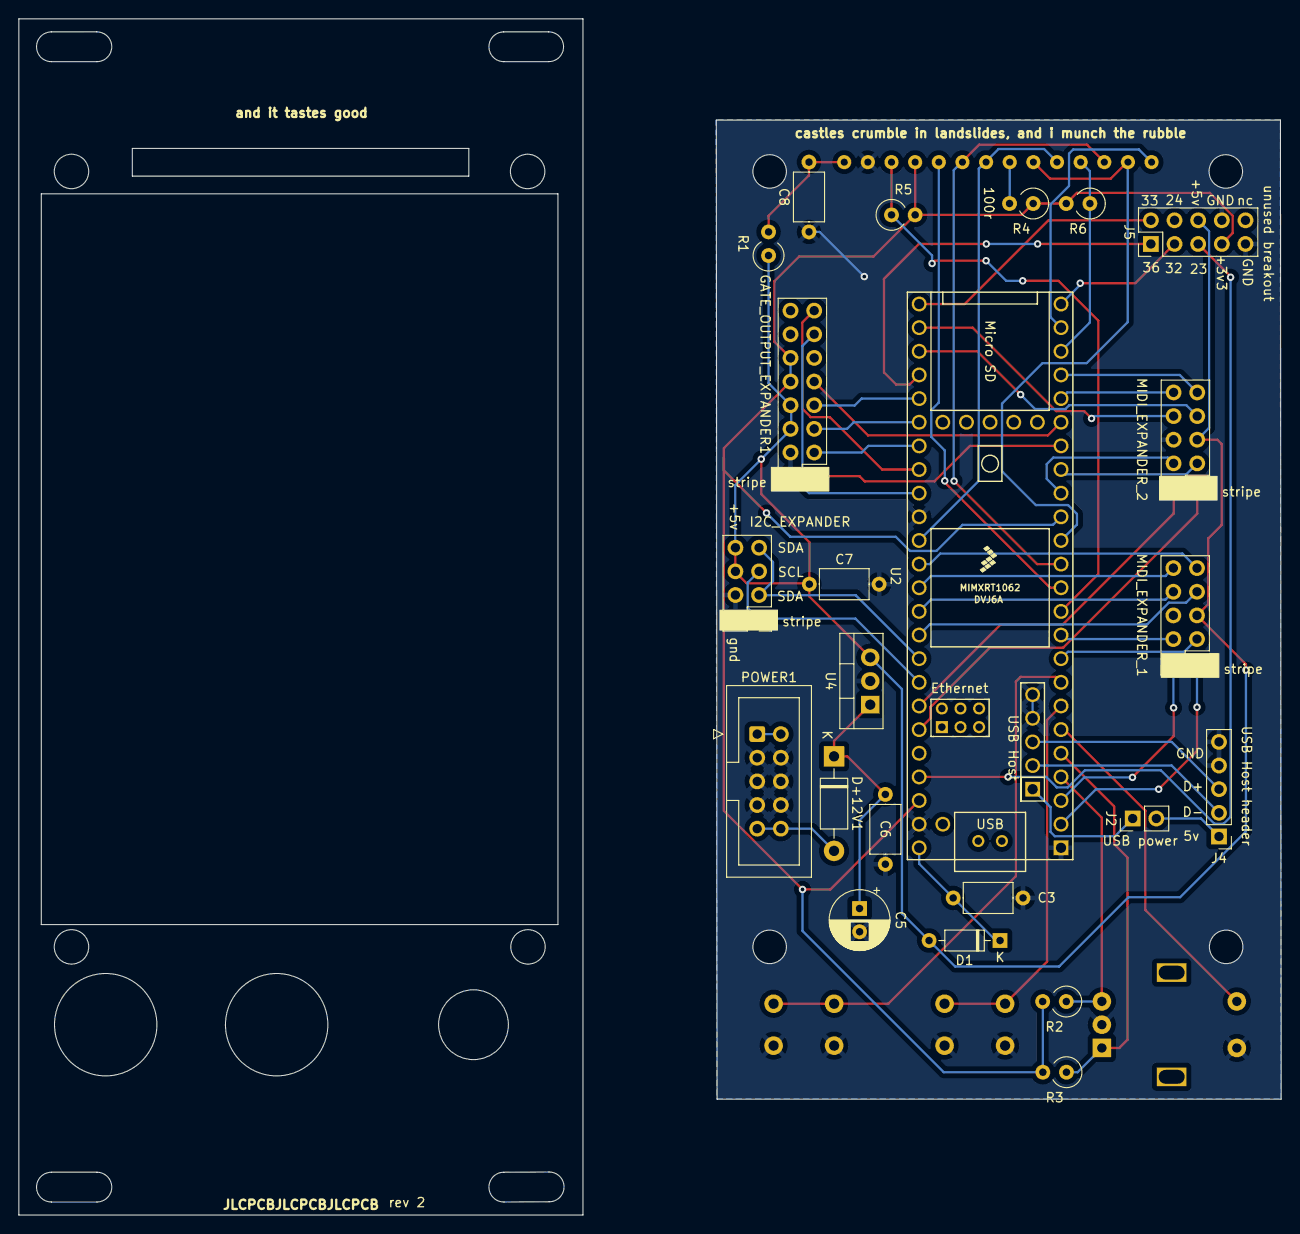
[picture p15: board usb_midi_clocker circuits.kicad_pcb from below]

Board: 2 copper layers, 60.7 x 105.2 mm, 27 parts (23 on the bottom side), 54 nets.

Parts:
C3, C8: C_Small; C_Axial_L5.1mm_D3.1mm_P7.50mm_Horizontal
C5: C_Polarized_Small; CP_Radial_D6.3mm_P2.50mm
C6: 330nF; C_Axial_L5.1mm_D3.1mm_P7.50mm_Horizontal
C7: 100nF; C_Axial_L5.1mm_D3.1mm_P7.50mm_Horizontal
D1: 1N4148; D_DO-35_SOD27_P7.62mm_Horizontal
D+12V1: 1N5817; D_DO-41_SOD81_P10.16mm_Horizontal
GATE_OUTPUT_EXPANDER1: 16 pin header; PinHeader_2x08_P2.54mm_Vertical
I2C_EXPANDER: 8 pin header; PinHeader_2x04_P2.54mm_Vertical
J2: USB power; PinHeader_1x02_P2.54mm_Vertical
J4: USB Host header; PinHeader_1x05_P2.54mm_Vertical
J5: Conn_01x09_Pin; PinHeader_2x05_P2.54mm_Vertical
MIDI_EXPANDER_1, MIDI_EXPANDER_2: Conn_02x05_Counter_Clockwise; PinHeader_2x05_P2.54mm_Vertical
POWER1: Eurorack power header; IDC-Header_2x05_P2.54mm_Vertical
R1: 100R; R_Axial_DIN0309_L9.0mm_D3.2mm_P2.54mm_Vertical
R2, R3, R5, R6: R; R_Axial_DIN0309_L9.0mm_D3.2mm_P2.54mm_Vertical
R4: 100r; R_Axial_DIN0309_L9.0mm_D3.2mm_P2.54mm_Vertical
SW1: Rotary_Encoder_Switch; RotaryEncoder_Alps_EC11E-Switch_Vertical_H20mm
SW2: SW_Push_Back; SW_PUSH_6mm_H13mm
SW3: SW_Push_Select; SW_PUSH_6mm_H13mm
U2: Teensy4.1; Teensy41
U3: TFT_320x240; doctea ili9341 3.2
U4: L7805; TO-220-3_Vertical

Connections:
+3V3: GATE_OUTPUT_EXPANDER1.10, GATE_OUTPUT_EXPANDER1.12, J5.7, R2.2, R3.2, R4.1, R5.2, R6.2, U2.15 (3V3), U2.46 (3V3), U3.4 (RST)
+5V: C7.1, D1.2 (A), GATE_OUTPUT_EXPANDER1.6, GATE_OUTPUT_EXPANDER1.8, I2C_EXPANDER.6, I2C_EXPANDER.8, J5.6, MIDI_EXPANDER_1.5, MIDI_EXPANDER_2.5, R1.1, U4.3 (OUT)
+12V: C5.1, C6.1, D+12V1.1 (K), U4.1 (IN)
External CS1: GATE_OUTPUT_EXPANDER1.5, U2.30 (38_CS1_IN1)
External CS2: GATE_OUTPUT_EXPANDER1.7, U2.29 (37_CS)
GND: C3.2, C5.2, C6.2, C7.2, C8.1, GATE_OUTPUT_EXPANDER1.2, GATE_OUTPUT_EXPANDER1.4, I2C_EXPANDER.2, I2C_EXPANDER.4, J4.4, J4.5, J5.8, J5.9, MIDI_EXPANDER_1.6, MIDI_EXPANDER_2.6, POWER1.3, POWER1.4, POWER1.5, POWER1.6, POWER1.7, POWER1.8, SW1.C, SW1.S2, SW2.2, SW3.2, U2.1 (GND), U2.34 (GND), U2.47 (GND), U2.58 (GND), U2.59 (GND), U3.2 (GND), U4.2 (GND)
Gate SPI MISO: GATE_OUTPUT_EXPANDER1.3, U2.31 (39_MISO1_OUT1A)
Gate SPI MOSI: GATE_OUTPUT_EXPANDER1.1, U2.18 (26_A12_MOSI1)
Gate SPI SCK: GATE_OUTPUT_EXPANDER1.9, U2.19 (27_A13_SCK1)
INT_1: GATE_OUTPUT_EXPANDER1.15, U2.32 (40_A16)
INT_2: GATE_OUTPUT_EXPANDER1.13, U2.33 (41_A17)
MIDI_1_RX: MIDI_EXPANDER_1.1, U2.2 (0_RX1_CRX2_CS1)
MIDI_1_TX: MIDI_EXPANDER_1.2, U2.3 (1_TX1_CTX2_MISO1)
MIDI_2_RX: MIDI_EXPANDER_1.3, U2.9 (7_RX2_OUT1A)
MIDI_2_TX: MIDI_EXPANDER_1.4, U2.10 (8_TX2_IN1)
MIDI_3_RX: MIDI_EXPANDER_1.10, U2.37 (15_A1_RX3_SPDIF_IN)
MIDI_3_TX: MIDI_EXPANDER_1.9, U2.36 (14_A0_TX3_SPDIF_OUT)
MIDI_4_RX: MIDI_EXPANDER_1.8, U2.38 (16_A2_RX4_SCL1)
MIDI_4_TX: MIDI_EXPANDER_1.7, U2.39 (17_A3_TX4_SDA1)
MIDI_5_RX: MIDI_EXPANDER_2.1, U2.43 (21_A7_RX5_BCLK1)
MIDI_5_TX: MIDI_EXPANDER_2.2, U2.42 (20_A6_TX5_LRCLK1)
MIDI_6_RX: MIDI_EXPANDER_2.3, U2.17 (25_A11_RX6_SDA2)
MIDI_6_TX: MIDI_EXPANDER_2.4, U2.16 (24_A10_TX6_SCL2)
MIDI_7_RX: MIDI_EXPANDER_2.10, U2.20 (28_RX7)
MIDI_7_TX: MIDI_EXPANDER_2.9, U2.21 (29_TX7)
MIDI_8_RX: MIDI_EXPANDER_2.8, U2.26 (34_RX8)
MIDI_8_TX: MIDI_EXPANDER_2.7, U2.27 (35_TX8)
unnamed: C3.1, D1.1 (K), U2.48 (VIN)
unnamed: D+12V1.2 (A), POWER1.9, POWER1.10
unnamed: J2.1, U2.55 (5V)
unnamed: J2.2, J4.1
unnamed: J4.2, U2.56 (D-)
unnamed: J4.3, U2.57 (D+)
unnamed: POWER1.1, POWER1.2
unnamed: R2.1, SW1.B, U2.4 (2_OUT2)
unnamed: R3.1, SW1.A, U2.5 (3_LRCLK2)
unnamed: SW1.S1, U2.6 (4_BCLK2)
unnamed: SW2.1, U2.7 (5_IN2)
unnamed: SW3.1, U2.8 (6_OUT1D)
unnamed: R4.2, U3.8 (LED)
unnamed: C8.2, R1.2, U3.1 (VCC)
TFT CS: R5.1, U2.11 (9_OUT1C), U3.3 (CS)
TFT DC: U2.12 (10_CS_MQSR), U3.5 (DC)
TFT SPI MISO: U2.14 (12_MISO_MQSL), U3.9 (MISO), U3.13
TFT SPI MOSI: U2.13 (11_MOSI_CTX1), U3.6 (MOSI), U3.12
TFT SPI SCK: U2.35 (13_SCK_LED), U3.7 (SCK), U3.10
Touch CS: R6.1, U2.22 (30_CRX3), U3.11
Touch IRQ: U2.23 (31_CTX3), U3.14
i2c SCL: I2C_EXPANDER.1, I2C_EXPANDER.5, U2.41 (19_A5_SCL)
i2c SDA: I2C_EXPANDER.3, I2C_EXPANDER.7, U2.40 (18_A4_SDA)
unused_pin_23: J5.5, U2.45 (23_A9_CRX1_MCLK1)
unused_pin_32: J5.3, U2.24 (32_OUT1B)
unused_pin_33: J5.2, U2.25 (33_MCLK2)
unused_pin_36: J5.1, U2.28 (36_CS)

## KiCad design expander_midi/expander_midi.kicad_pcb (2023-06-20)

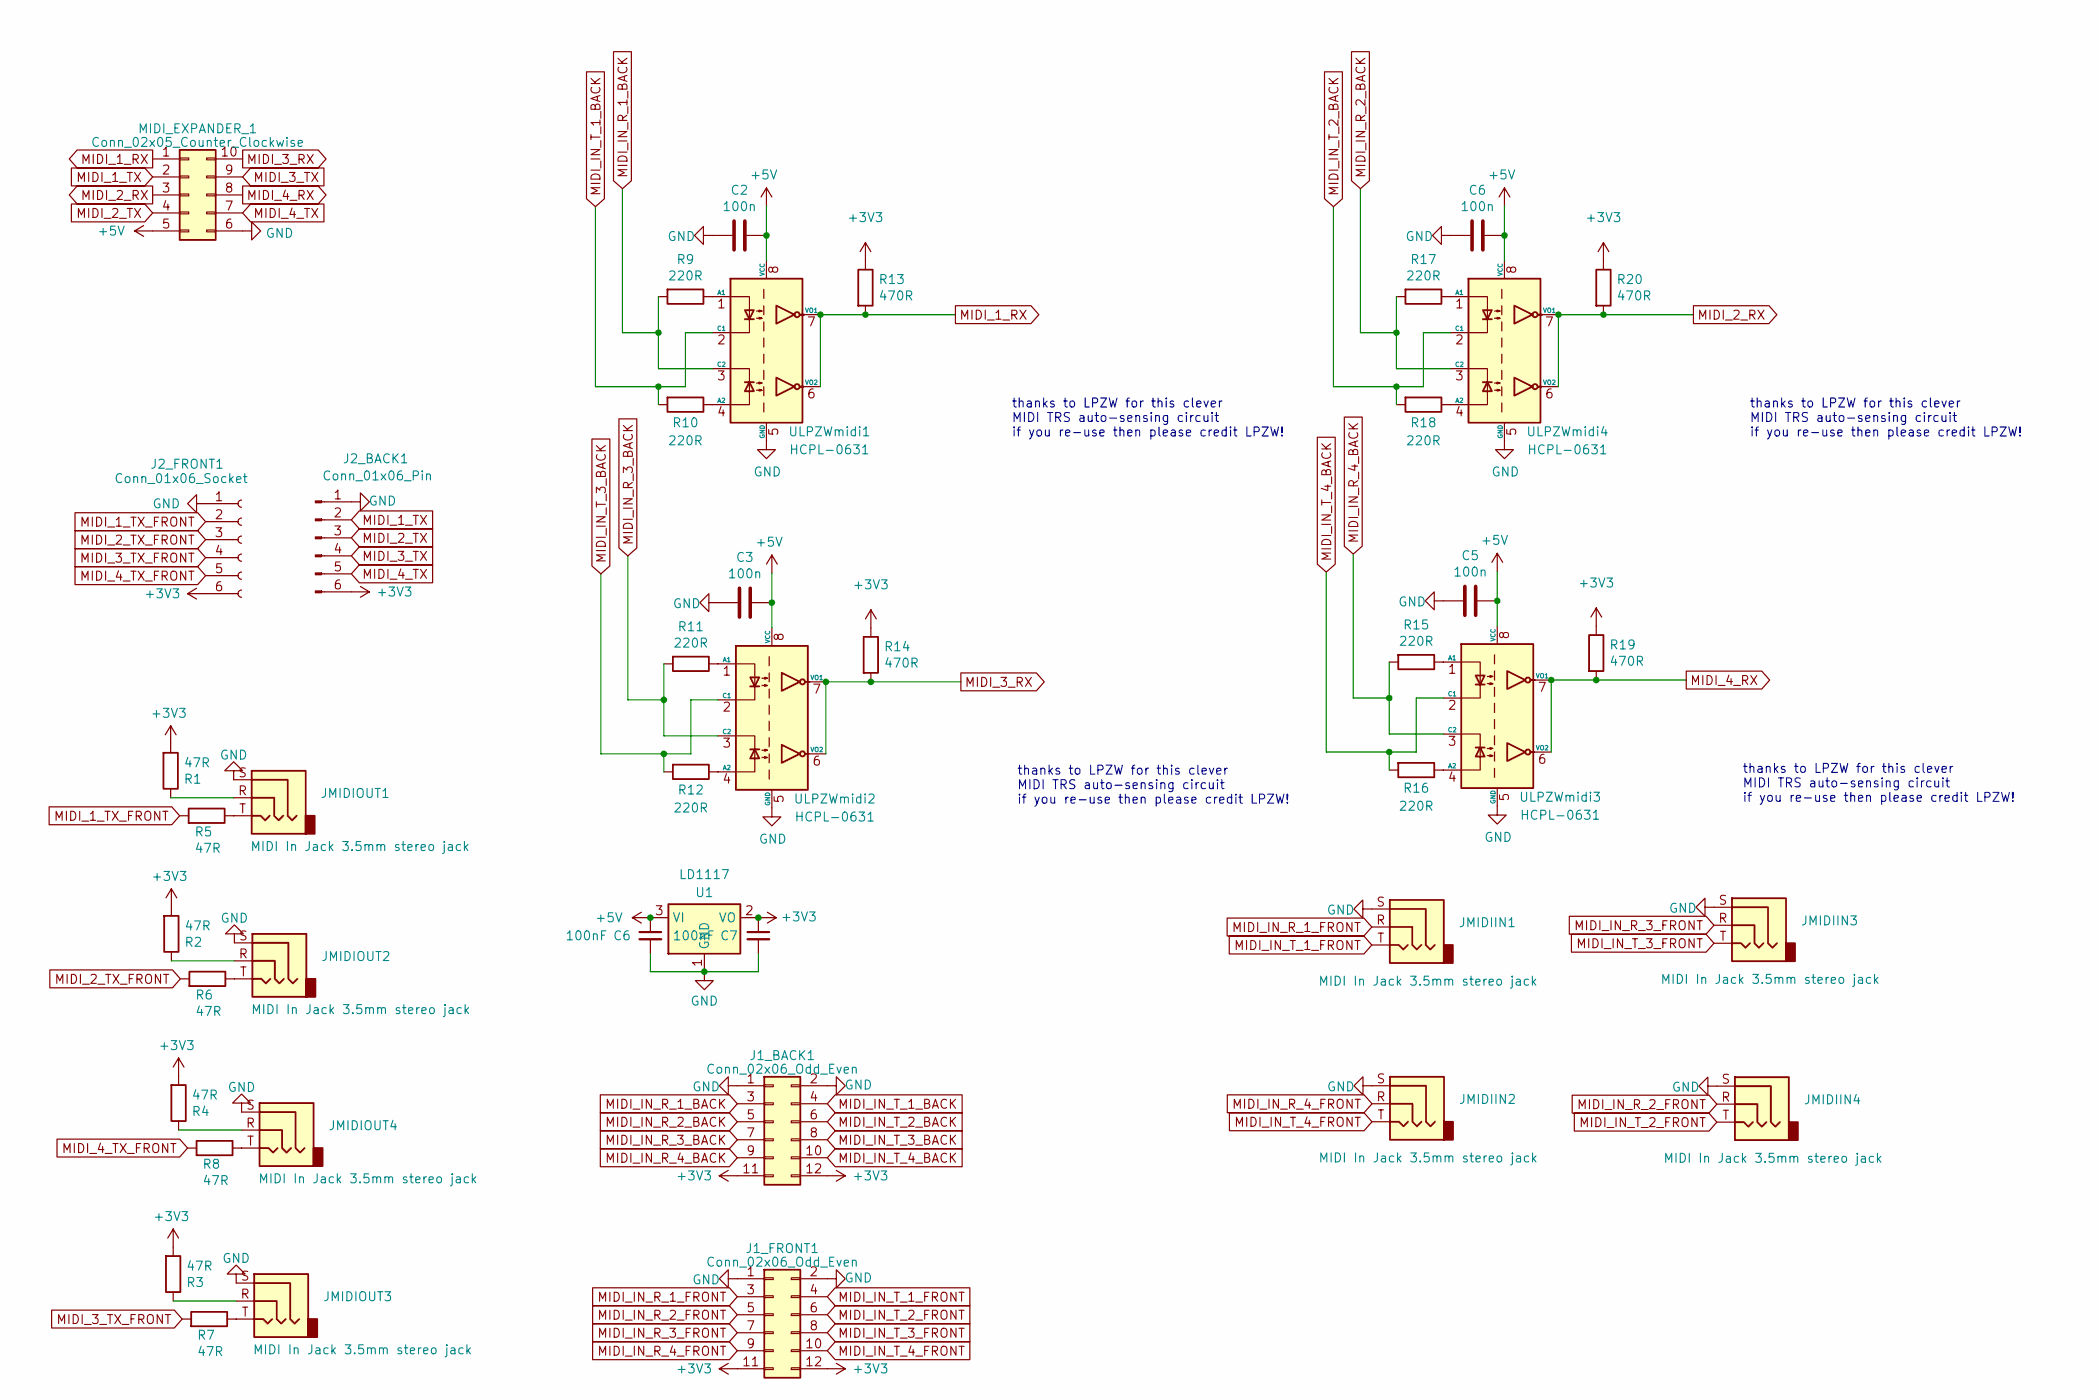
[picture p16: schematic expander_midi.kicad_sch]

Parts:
C2, C3, C5: 100n; C_Axial_L5.1mm_D3.1mm_P7.50mm_Horizontal
C6, C7: 100nF; C_Axial_L5.1mm_D3.1mm_P7.50mm_Horizontal
J1_BACK1: Conn_02x06_Odd_Even; PinHeader_2x06_P2.54mm_Vertical
J1_FRONT1: Conn_02x06_Odd_Even; PinSocket_2x06_P2.54mm_Vertical
J2_BACK1: Conn_01x06_Pin; PinHeader_1x06_P2.54mm_Vertical
J2_FRONT1: Conn_01x06_Socket; PinSocket_1x06_P2.54mm_Vertical
JMIDIIN1, JMIDIIN2, JMIDIIN3, JMIDIIN4: MIDI In Jack 3.5mm stereo jack; Jack_3.5mm_QingPu_WQP-PJ398SM_TRS_Vertical_CircularHoles
JMIDIOUT1, JMIDIOUT2, JMIDIOUT3, JMIDIOUT4: MIDI In Jack 3.5mm stereo jack; Jack_3.5mm_QingPu_WQP-PJ398SM_TRS_Vertical_CircularHoles
MIDI_EXPANDER_1: Conn_02x05_Counter_Clockwise; PinHeader_2x05_P2.54mm_Vertical
R1, R2, R3, R4, R5, R6, R7, R8: 47R; R_Axial_DIN0207_L6.3mm_D2.5mm_P7.62mm_Horizontal
R9, R10, R11, R12, R15, R16, R17, R18: 220R; R_Axial_DIN0207_L6.3mm_D2.5mm_P7.62mm_Horizontal
R13, R14, R19, R20: 470R; R_Axial_DIN0207_L6.3mm_D2.5mm_P7.62mm_Horizontal
U1: LD1117; SOT-223-3_TabPin2
ULPZWmidi1, ULPZWmidi2, ULPZWmidi3, ULPZWmidi4: HCPL-0631; SOIC-8_3.9x4.9mm_P1.27mm

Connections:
+3V3: J1_BACK1.11, J1_BACK1.12, J1_FRONT1.11, J1_FRONT1.12, J2_BACK1.6, J2_FRONT1.6, R1.2, R2.2, R3.2, R4.2, R13.1, R14.1, R19.1, R20.1, U1.2 (VO); also elsewhere on the board
+5V: C2.1, C3.1, C5.1, C6.1, MIDI_EXPANDER_1.5, U1.3 (VI), ULPZWmidi1.8 (VCC), ULPZWmidi2.8 (VCC), ULPZWmidi3.8 (VCC), ULPZWmidi4.8 (VCC); also elsewhere on the board
GND: C2.2, C3.2, C5.2, C6.2, J1_BACK1.1, J1_BACK1.2, J1_FRONT1.1, J1_FRONT1.2, J2_BACK1.1, J2_FRONT1.1, JMIDIIN1.S, JMIDIIN2.S, JMIDIIN3.S, JMIDIIN4.S, JMIDIOUT1.S, JMIDIOUT2.S, JMIDIOUT3.S, JMIDIOUT4.S, MIDI_EXPANDER_1.6, U1.1 (GND), ULPZWmidi1.5 (GND), ULPZWmidi2.5 (GND), ULPZWmidi3.5 (GND), ULPZWmidi4.5 (GND); also elsewhere on the board
MIDI_1_RX: MIDI_EXPANDER_1.1, R13.2, ULPZWmidi1.6 (VO2), ULPZWmidi1.7 (VO1)
MIDI_1_TX: J2_BACK1.2, MIDI_EXPANDER_1.2
MIDI_1_TX_FRONT: J2_FRONT1.2, R5.2
MIDI_2_RX: MIDI_EXPANDER_1.3, R20.2, ULPZWmidi4.6 (VO2), ULPZWmidi4.7 (VO1)
MIDI_2_TX: J2_BACK1.3, MIDI_EXPANDER_1.4
MIDI_2_TX_FRONT: J2_FRONT1.3, R6.2
MIDI_3_RX: MIDI_EXPANDER_1.10, R14.2, ULPZWmidi2.6 (VO2), ULPZWmidi2.7 (VO1)
MIDI_3_TX: J2_BACK1.4, MIDI_EXPANDER_1.9
MIDI_3_TX_FRONT: J2_FRONT1.4, R7.2
MIDI_4_RX: MIDI_EXPANDER_1.8, R19.2, ULPZWmidi3.6 (VO2), ULPZWmidi3.7 (VO1)
MIDI_4_TX: J2_BACK1.5, MIDI_EXPANDER_1.7
MIDI_4_TX_FRONT: J2_FRONT1.5, R8.2
MIDI_IN_R_1_BACK: J1_BACK1.3, R9.2, ULPZWmidi1.3 (C2)
MIDI_IN_R_1_FRONT: J1_FRONT1.3, JMIDIIN1.R
MIDI_IN_R_2_BACK: J1_BACK1.5, R17.2, ULPZWmidi4.3 (C2)
MIDI_IN_R_2_FRONT: J1_FRONT1.5, JMIDIIN4.R
MIDI_IN_R_3_BACK: J1_BACK1.7, R11.2, ULPZWmidi2.3 (C2)
MIDI_IN_R_3_FRONT: J1_FRONT1.7, JMIDIIN3.R
MIDI_IN_R_4_BACK: J1_BACK1.9, R15.2, ULPZWmidi3.3 (C2)
MIDI_IN_R_4_FRONT: J1_FRONT1.9, JMIDIIN2.R
MIDI_IN_T_1_BACK: J1_BACK1.4, R10.2, ULPZWmidi1.2 (C1)
MIDI_IN_T_1_FRONT: J1_FRONT1.4, JMIDIIN1.T
MIDI_IN_T_2_BACK: J1_BACK1.6, R18.2, ULPZWmidi4.2 (C1)
MIDI_IN_T_2_FRONT: J1_FRONT1.6, JMIDIIN4.T
MIDI_IN_T_3_BACK: J1_BACK1.8, R12.2, ULPZWmidi2.2 (C1)
MIDI_IN_T_3_FRONT: J1_FRONT1.8, JMIDIIN3.T
MIDI_IN_T_4_BACK: J1_BACK1.10, R16.2, ULPZWmidi3.2 (C1)
MIDI_IN_T_4_FRONT: J1_FRONT1.10, JMIDIIN2.T
unnamed: JMIDIOUT1.R, R1.1
unnamed: JMIDIOUT1.T, R5.1
unnamed: JMIDIOUT2.R, R2.1
unnamed: JMIDIOUT2.T, R6.1
unnamed: JMIDIOUT3.R, R3.1
unnamed: JMIDIOUT3.T, R7.1
unnamed: JMIDIOUT4.R, R4.1
unnamed: JMIDIOUT4.T, R8.1
unnamed: R9.1, ULPZWmidi1.1 (A1)
unnamed: R10.1, ULPZWmidi1.4 (A2)
unnamed: R11.1, ULPZWmidi2.1 (A1)
unnamed: R12.1, ULPZWmidi2.4 (A2)
unnamed: R15.1, ULPZWmidi3.1 (A1)
unnamed: R16.1, ULPZWmidi3.4 (A2)
unnamed: R17.1, ULPZWmidi4.1 (A1)
unnamed: R18.1, ULPZWmidi4.4 (A2)

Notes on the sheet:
thanks to LPZW for this clever MIDI TRS auto-sensing circuit if you re-use then please credit LPZW!

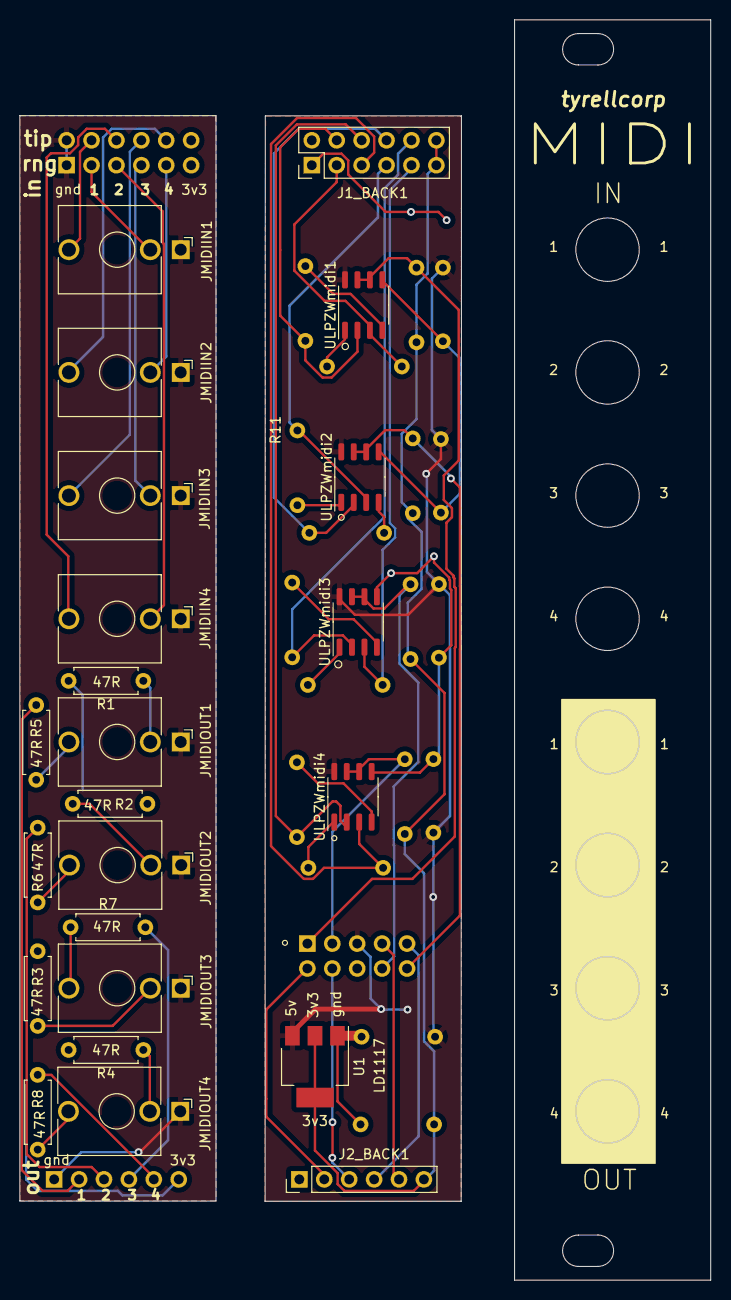
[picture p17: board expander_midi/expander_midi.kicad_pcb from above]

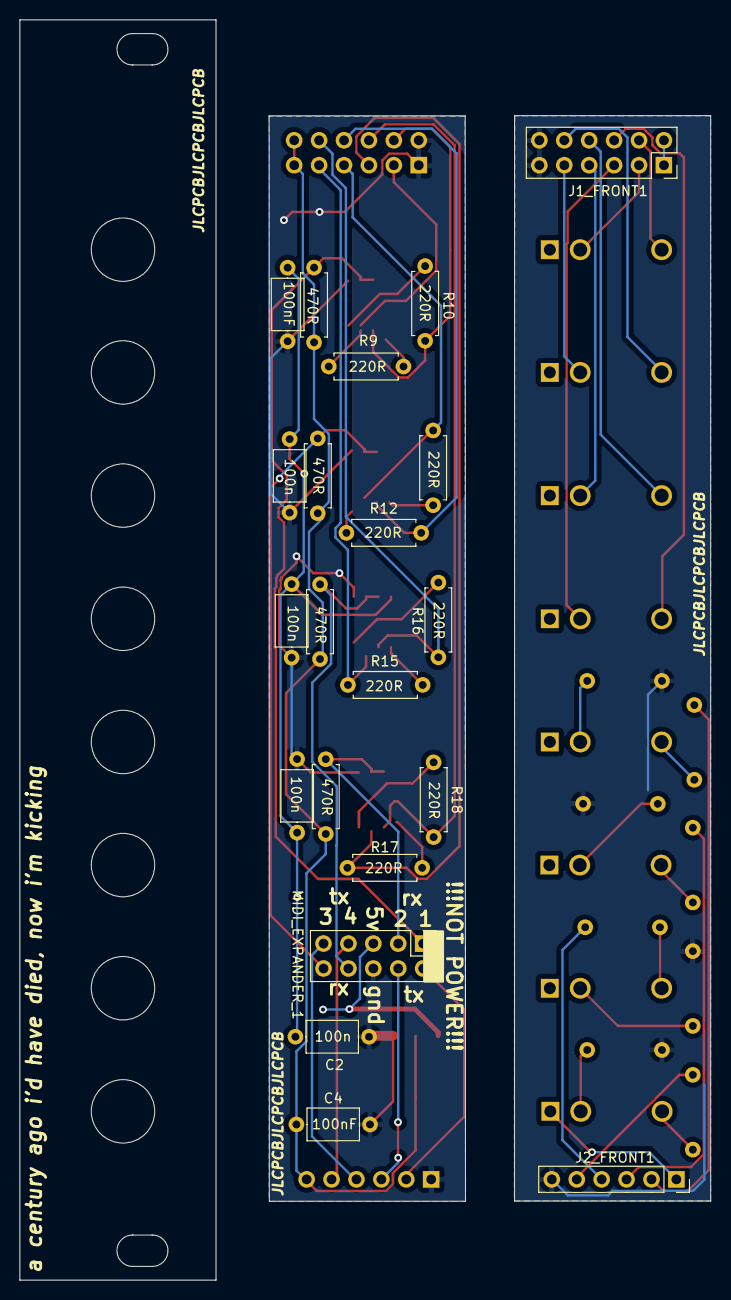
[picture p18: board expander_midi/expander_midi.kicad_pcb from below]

Board: 2 copper layers, 70.4 x 128.5 mm, 44 parts (21 on the bottom side), 47 nets.

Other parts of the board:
C1, C4: 100nF; C_Axial_L5.1mm_D3.1mm_P7.50mm_Horizontal

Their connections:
+3V3: C4.1; also elsewhere on the board
+5V: C1.1; also elsewhere on the board
GND: C1.2, C4.2; also elsewhere on the board

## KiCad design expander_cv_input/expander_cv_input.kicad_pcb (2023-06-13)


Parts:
ADS1015_1_DIG1, ADS1015_2_DIG1: ADS1015 digital side; PinSocket_1x05_P2.54mm_Vertical
ASD1015_1_ANA1, ASD1015_2_ANA1: ADS1015 analog side; PinSocket_1x05_P2.54mm_Vertical
C1, C2: 100n; C_Disc_D5.0mm_W2.5mm_P5.00mm
CV_INPUT_I2C_EXPANDER_MAIN1: 8 pin header; PinHeader_2x04_P2.54mm_Vertical
JACK1, JACK2, JACK3, JACK4, JACK5, JACK6: AudioJack2_SwitchT; Jack_3.5mm_QingPu_WQP-PJ398SM_Vertical_CircularHoles

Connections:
+5V: ADS1015_1_DIG1.1, ADS1015_2_DIG1.1, ASD1015_1_ANA1.1, ASD1015_2_ANA1.1, C1.2, C2.2; also elsewhere on the board
A0 input Frontboard: ASD1015_1_ANA1.2, JACK1.T
A1 input Frontboard: ASD1015_1_ANA1.3, JACK2.T
A2 input Frontboard: ASD1015_1_ANA1.4, JACK3.T
A3 input Frontboard: ASD1015_2_ANA1.2, JACK4.T
A4 input Frontboard: ASD1015_2_ANA1.3, JACK5.T
A5 input Frontboard: ASD1015_2_ANA1.4, JACK6.T
ADS 1 Interrupt: ADS1015_1_DIG1.4
ADS 2 Interrupt: ADS1015_2_DIG1.4
CV GND: ADS1015_1_DIG1.5, ADS1015_2_DIG1.5, ASD1015_1_ANA1.5, ASD1015_2_ANA1.5, C1.1, C2.1, JACK1.S, JACK1.TN, JACK2.S, JACK2.TN, JACK3.S, JACK3.TN, JACK4.S, JACK4.TN, JACK5.S, JACK5.TN, JACK6.S, JACK6.TN; also elsewhere on the board
i2c SCL: ADS1015_1_DIG1.3, ADS1015_2_DIG1.3; also elsewhere on the board
i2c SDA: ADS1015_1_DIG1.2, ADS1015_2_DIG1.2; also elsewhere on the board



Board: 2 copper layers, 61.8 x 128.5 mm, 14 parts (8 on the bottom side), 10 nets.

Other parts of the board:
CV_INPUT_I2C_EXPANDER1, CV_INPUT_I2C_THRU1: 8 pin header; PinHeader_2x04_P2.54mm_Vertical

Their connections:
+5V: CV_INPUT_I2C_EXPANDER1.6, CV_INPUT_I2C_EXPANDER1.8, CV_INPUT_I2C_THRU1.6, CV_INPUT_I2C_THRU1.8; also elsewhere on the board
CV GND: CV_INPUT_I2C_EXPANDER1.2, CV_INPUT_I2C_EXPANDER1.4, CV_INPUT_I2C_THRU1.2, CV_INPUT_I2C_THRU1.4; also elsewhere on the board
i2c SCL: CV_INPUT_I2C_EXPANDER1.1, CV_INPUT_I2C_EXPANDER1.5, CV_INPUT_I2C_THRU1.1, CV_INPUT_I2C_THRU1.5; also elsewhere on the board
i2c SDA: CV_INPUT_I2C_EXPANDER1.3, CV_INPUT_I2C_EXPANDER1.7, CV_INPUT_I2C_THRU1.3, CV_INPUT_I2C_THRU1.7; also elsewhere on the board

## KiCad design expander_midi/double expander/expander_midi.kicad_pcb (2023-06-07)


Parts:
C1, C2, C3, C4, C5, C6, C7, C8: 100n; C_0805_2012Metric
JMIDIIN1, JMIDIIN2, JMIDIIN3, JMIDIIN4, JMIDIIN5, JMIDIIN6, JMIDIIN7, JMIDIIN8: MIDI In Jack 3.5mm stereo jack; Jack_3.5mm_QingPu_WQP-PJ398SM_TRS_Vertical_CircularHoles
JMIDIOUT1, JMIDIOUT2, JMIDIOUT3, JMIDIOUT4, JMIDIOUT5, JMIDIOUT6, JMIDIOUT7, JMIDIOUT8: MIDI In Jack 3.5mm stereo jack; Jack_3.5mm_QingPu_WQP-PJ398SM_TRS_Vertical_CircularHoles
MIDI_EXPANDER_MAIN1: 20 pin header; PinHeader_2x10_P2.54mm_Vertical
R1, R2, R4, R5, R7, R8, R10, R11, R13, R14, R15, R16, R19, R20, R21, R22: 220R; R_0805_2012Metric
R3, R6, R9, R12, R17, R18, R23, R24: 470R; R_0805_2012Metric
R25, R26, R27, R28, R29, R30, R31, R32, R33, R34, R35, R36, R37, R38, R39, R40: 47R; R_0805_2012Metric
ULPZWmidi1, ULPZWmidi2, ULPZWmidi3, ULPZWmidi4, ULPZWmidi5, ULPZWmidi6, ULPZWmidi7, ULPZWmidi8: HCPL-0631; SOIC-8_3.9x4.9mm_P1.27mm

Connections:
+3V3: MIDI_EXPANDER_MAIN1.12, R3.1, R6.1, R9.1, R12.1, R17.1, R18.1, R23.1, R24.1, R25.2, R27.2, R29.2, R31.2, R33.2, R34.2, R35.2, R36.2
+5V: C1.1, C2.1, C3.1, C4.1, C5.1, C6.1, C7.1, C8.1, MIDI_EXPANDER_MAIN1.11, ULPZWmidi1.8 (VCC), ULPZWmidi2.8 (VCC), ULPZWmidi3.8 (VCC), ULPZWmidi4.8 (VCC), ULPZWmidi5.8 (VCC), ULPZWmidi6.8 (VCC), ULPZWmidi7.8 (VCC), ULPZWmidi8.8 (VCC)
GND: C1.2, C2.2, C3.2, C4.2, C5.2, C6.2, C7.2, C8.2, JMIDIIN1.S, JMIDIIN2.S, JMIDIIN3.S, JMIDIIN4.S, JMIDIIN5.S, JMIDIIN6.S, JMIDIIN7.S, JMIDIIN8.S, JMIDIOUT1.S, JMIDIOUT2.S, JMIDIOUT3.S, JMIDIOUT4.S, JMIDIOUT5.S, JMIDIOUT6.S, JMIDIOUT7.S, JMIDIOUT8.S, MIDI_EXPANDER_MAIN1.9, MIDI_EXPANDER_MAIN1.10, ULPZWmidi1.5 (GND), ULPZWmidi2.5 (GND), ULPZWmidi3.5 (GND), ULPZWmidi4.5 (GND), ULPZWmidi5.5 (GND), ULPZWmidi6.5 (GND), ULPZWmidi7.5 (GND), ULPZWmidi8.5 (GND)
MIDI_1_RX: MIDI_EXPANDER_MAIN1.1, R3.2, ULPZWmidi1.6 (VO2), ULPZWmidi1.7 (VO1)
MIDI_1_TX: MIDI_EXPANDER_MAIN1.2, R26.2
MIDI_2_RX: MIDI_EXPANDER_MAIN1.3, R6.2, ULPZWmidi2.6 (VO2), ULPZWmidi2.7 (VO1)
MIDI_2_TX: MIDI_EXPANDER_MAIN1.4, R38.2
MIDI_3_RX: MIDI_EXPANDER_MAIN1.5, R9.2, ULPZWmidi3.6 (VO2), ULPZWmidi3.7 (VO1)
MIDI_3_TX: MIDI_EXPANDER_MAIN1.6, R28.2
MIDI_4_RX: MIDI_EXPANDER_MAIN1.7, R12.2, ULPZWmidi4.6 (VO2), ULPZWmidi4.7 (VO1)
MIDI_4_TX: MIDI_EXPANDER_MAIN1.8, R40.2
MIDI_5_RX: MIDI_EXPANDER_MAIN1.20, R17.2, ULPZWmidi5.6 (VO2), ULPZWmidi5.7 (VO1)
MIDI_5_TX: MIDI_EXPANDER_MAIN1.19, R30.2
MIDI_6_RX: MIDI_EXPANDER_MAIN1.18, R24.2, ULPZWmidi8.6 (VO2), ULPZWmidi8.7 (VO1)
MIDI_6_TX: MIDI_EXPANDER_MAIN1.17, R39.2
MIDI_7_RX: MIDI_EXPANDER_MAIN1.16, R18.2, ULPZWmidi6.6 (VO2), ULPZWmidi6.7 (VO1)
MIDI_7_TX: MIDI_EXPANDER_MAIN1.15, R32.2
MIDI_8_RX: MIDI_EXPANDER_MAIN1.14, R23.2, ULPZWmidi7.6 (VO2), ULPZWmidi7.7 (VO1)
MIDI_8_TX: MIDI_EXPANDER_MAIN1.13, R37.2
unnamed: JMIDIOUT1.R, R25.1
unnamed: JMIDIOUT1.T, R26.1
unnamed: JMIDIOUT2.R, R27.1
unnamed: JMIDIOUT2.T, R28.1
unnamed: JMIDIOUT3.R, R29.1
unnamed: JMIDIOUT3.T, R30.1
unnamed: JMIDIOUT4.R, R31.1
unnamed: JMIDIOUT4.T, R32.1
unnamed: JMIDIOUT5.R, R33.1
unnamed: JMIDIOUT5.T, R37.1
unnamed: JMIDIOUT6.R, R34.1
unnamed: JMIDIOUT6.T, R38.1
unnamed: JMIDIOUT7.R, R35.1
unnamed: JMIDIOUT7.T, R39.1
unnamed: JMIDIOUT8.R, R36.1
unnamed: JMIDIOUT8.T, R40.1
unnamed: R1.1, ULPZWmidi1.1 (A1)
unnamed: R2.1, ULPZWmidi1.4 (A2)
unnamed: JMIDIIN1.T, R2.2, ULPZWmidi1.2 (C1)
unnamed: JMIDIIN1.R, R1.2, ULPZWmidi1.3 (C2)
unnamed: R4.1, ULPZWmidi2.1 (A1)
unnamed: R5.1, ULPZWmidi2.4 (A2)
unnamed: JMIDIIN2.T, R5.2, ULPZWmidi2.2 (C1)
unnamed: JMIDIIN2.R, R4.2, ULPZWmidi2.3 (C2)
unnamed: R7.1, ULPZWmidi3.1 (A1)
unnamed: R8.1, ULPZWmidi3.4 (A2)
unnamed: JMIDIIN3.T, R8.2, ULPZWmidi3.2 (C1)
unnamed: JMIDIIN3.R, R7.2, ULPZWmidi3.3 (C2)
unnamed: R10.1, ULPZWmidi4.1 (A1)
unnamed: R11.1, ULPZWmidi4.4 (A2)
unnamed: JMIDIIN4.T, R11.2, ULPZWmidi4.2 (C1)
unnamed: JMIDIIN4.R, R10.2, ULPZWmidi4.3 (C2)
unnamed: R13.1, ULPZWmidi5.1 (A1)
unnamed: R14.1, ULPZWmidi5.4 (A2)
unnamed: JMIDIIN5.T, R14.2, ULPZWmidi5.2 (C1)
unnamed: JMIDIIN5.R, R13.2, ULPZWmidi5.3 (C2)
unnamed: R15.1, ULPZWmidi6.1 (A1)
unnamed: R16.1, ULPZWmidi6.4 (A2)
unnamed: JMIDIIN6.T, R16.2, ULPZWmidi6.2 (C1)
unnamed: JMIDIIN6.R, R15.2, ULPZWmidi6.3 (C2)
unnamed: R19.1, ULPZWmidi7.1 (A1)
unnamed: R20.1, ULPZWmidi7.4 (A2)
unnamed: JMIDIIN7.T, R20.2, ULPZWmidi7.2 (C1)
unnamed: JMIDIIN7.R, R19.2, ULPZWmidi7.3 (C2)
unnamed: R21.1, ULPZWmidi8.1 (A1)
unnamed: R22.1, ULPZWmidi8.4 (A2)
unnamed: JMIDIIN8.T, R22.2, ULPZWmidi8.2 (C1)
unnamed: JMIDIIN8.R, R21.2, ULPZWmidi8.3 (C2)

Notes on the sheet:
thanks to LPZW for this clever MIDI TRS auto-sensing circuit if you re-use then please credit LPZW!



Board: 2 copper layers, 40.2 x 106.1 mm, 73 parts (45 on the bottom side), 67 nets.

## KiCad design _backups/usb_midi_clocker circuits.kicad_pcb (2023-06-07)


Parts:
C3, C8: C_Small; C_Axial_L5.1mm_D3.1mm_P7.50mm_Horizontal
C5: C_Polarized_Small; CP_Radial_D6.3mm_P2.50mm
C6: 10uF; C_Axial_L5.1mm_D3.1mm_P7.50mm_Horizontal
C7: 1uF; C_Axial_L5.1mm_D3.1mm_P7.50mm_Horizontal
CV_INPUT_I2C_EXPANDER_MAIN1: 8 pin header; PinHeader_2x04_P2.54mm_Vertical
D1: 1N4148; D_DO-35_SOD27_P7.62mm_Horizontal
D+12V1: 1N5817; D_DO-41_SOD81_P10.16mm_Horizontal
GATE_OUTPUT_EXPANDER1: 16 pin header; PinHeader_2x08_P2.54mm_Vertical
J1: SD card breakout; PinHeader_2x04_P2.54mm_Vertical
J2: USB power; PinHeader_1x02_P2.54mm_Vertical
J3: PJS008U-3000-0
J4: USB Host header; PinHeader_1x05_P2.54mm_Vertical
MIDI_EXPANDER_MAIN1: 20 pin header; PinHeader_2x10_P2.54mm_Vertical
POWER1: Eurorack power header; IDC-Header_2x05_P2.54mm_Vertical
R1: 100R; R_Axial_DIN0207_L6.3mm_D2.5mm_P10.16mm_Horizontal
SW1: Rotary_Encoder_Switch; RotaryEncoder_Alps_EC11E-Switch_Vertical_H20mm
SW2: SW_Push_Back; SW_PUSH_6mm_H13mm
SW3: SW_Push_Select; SW_PUSH_6mm_H13mm
U1: L78L05_TO92; TO-92_Inline
U2: Teensy4.1; Teensy41
U3: TFT_320x240; TFT-320x240

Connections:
+3V3: GATE_OUTPUT_EXPANDER1.10, GATE_OUTPUT_EXPANDER1.12, MIDI_EXPANDER_MAIN1.12, U2.15 (3V3), U2.46 (3V3), U3.8 (LED)
+5V: C7.1, CV_INPUT_I2C_EXPANDER_MAIN1.6, CV_INPUT_I2C_EXPANDER_MAIN1.8, D1.2 (A), GATE_OUTPUT_EXPANDER1.6, GATE_OUTPUT_EXPANDER1.8, MIDI_EXPANDER_MAIN1.11, R1.1, U1.1 (VO)
+12V: C5.1, C6.1, D+12V1.1 (K), U1.3 (VI)
External CS1: GATE_OUTPUT_EXPANDER1.5, U2.30 (38_CS1_IN1)
External CS2: GATE_OUTPUT_EXPANDER1.7, U2.29 (37_CS)
GND: C3.2, C5.2, C6.2, C7.2, C8.1, CV_INPUT_I2C_EXPANDER_MAIN1.2, CV_INPUT_I2C_EXPANDER_MAIN1.4, GATE_OUTPUT_EXPANDER1.2, GATE_OUTPUT_EXPANDER1.4, J4.4, J4.5, MIDI_EXPANDER_MAIN1.9, MIDI_EXPANDER_MAIN1.10, POWER1.3, POWER1.4, POWER1.5, POWER1.6, POWER1.7, POWER1.8, SW1.C, SW1.S2, SW2.2, SW3.2, U1.2 (GND), U2.1 (GND), U2.34 (GND), U2.47 (GND), U2.58 (GND), U2.59 (GND), U3.2 (GND)
Gate SPI MISO: GATE_OUTPUT_EXPANDER1.3, U2.31 (39_MISO1_OUT1A)
Gate SPI MOSI: GATE_OUTPUT_EXPANDER1.1, U2.18 (26_A12_MOSI1)
Gate SPI SCK: GATE_OUTPUT_EXPANDER1.9, U2.19 (27_A13_SCK1)
INT_1: GATE_OUTPUT_EXPANDER1.15, U2.32 (40_A16)
INT_2: GATE_OUTPUT_EXPANDER1.13, U2.33 (41_A17)
MIDI_1_RX: MIDI_EXPANDER_MAIN1.1, U2.2 (0_RX1_CRX2_CS1)
MIDI_1_TX: MIDI_EXPANDER_MAIN1.2, U2.3 (1_TX1_CTX2_MISO1)
MIDI_2_RX: MIDI_EXPANDER_MAIN1.3, U2.9 (7_RX2_OUT1A)
MIDI_2_TX: MIDI_EXPANDER_MAIN1.4, U2.10 (8_TX2_IN1)
MIDI_3_RX: MIDI_EXPANDER_MAIN1.5, U2.37 (15_A1_RX3_SPDIF_IN)
MIDI_3_TX: MIDI_EXPANDER_MAIN1.6, U2.36 (14_A0_TX3_SPDIF_OUT)
MIDI_4_RX: MIDI_EXPANDER_MAIN1.7, U2.38 (16_A2_RX4_SCL1)
MIDI_4_TX: MIDI_EXPANDER_MAIN1.8, U2.39 (17_A3_TX4_SDA1)
MIDI_5_RX: MIDI_EXPANDER_MAIN1.20, U2.43 (21_A7_RX5_BCLK1)
MIDI_5_TX: MIDI_EXPANDER_MAIN1.19, U2.42 (20_A6_TX5_LRCLK1)
MIDI_6_RX: MIDI_EXPANDER_MAIN1.18, U2.17 (25_A11_RX6_SDA2)
MIDI_6_TX: MIDI_EXPANDER_MAIN1.17, U2.16 (24_A10_TX6_SCL2)
MIDI_7_RX: MIDI_EXPANDER_MAIN1.16, U2.20 (28_RX7)
MIDI_7_TX: MIDI_EXPANDER_MAIN1.15, U2.21 (29_TX7)
MIDI_8_RX: MIDI_EXPANDER_MAIN1.14, U2.26 (34_RX8)
MIDI_8_TX: MIDI_EXPANDER_MAIN1.13, U2.27 (35_TX8)
unnamed: C3.1, D1.1 (K), U2.48 (VIN)
unnamed: D+12V1.2 (A), POWER1.9, POWER1.10
unnamed: J1.1, J3.8 (DAT1)
unnamed: J1.2, J3.7 (DAT0)
unnamed: J1.3, J3.6 (VSS)
unnamed: J1.4, J3.5 (CLK)
unnamed: J1.5, J3.4 (VDD)
unnamed: J1.6, J3.3 (CMD)
unnamed: J1.7, J3.2 (CD/DAT3)
unnamed: J1.8, J3.1 (DAT2)
unnamed: J2.1, U2.55 (5V)
unnamed: J2.2, J4.1
unnamed: J4.2, U2.56 (D-)
unnamed: J4.3, U2.57 (D+)
unnamed: POWER1.1, POWER1.2
unnamed: SW1.B, U2.4 (2_OUT2)
unnamed: SW1.A, U2.5 (3_LRCLK2)
unnamed: SW1.S1, U2.6 (4_BCLK2)
unnamed: SW2.1, U2.7 (5_IN2)
unnamed: SW3.1, U2.8 (6_OUT1D)
unnamed: C8.2, R1.2, U3.1 (VCC)
TFT CS: U2.12 (10_CS_MQSR), U3.3 (CS)
TFT DC: U2.11 (9_OUT1C), U3.5 (DC)
TFT Reset: U2.23 (31_CTX3), U3.4 (RST)
TFT SPI MISO: U2.14 (12_MISO_MQSL), U3.9 (MISO), U3.13
TFT SPI MOSI: U2.13 (11_MOSI_CTX1), U3.6 (MOSI), U3.12
TFT SPI SCK: U2.35 (13_SCK_LED), U3.7 (SCK), U3.10
Touch CS: U2.22 (30_CRX3), U3.11
Touch IRQ: U2.44 (22_A8_CTX1), U3.14
i2c SCL: CV_INPUT_I2C_EXPANDER_MAIN1.1, CV_INPUT_I2C_EXPANDER_MAIN1.5, U2.41 (19_A5_SCL)
i2c SDA: CV_INPUT_I2C_EXPANDER_MAIN1.3, CV_INPUT_I2C_EXPANDER_MAIN1.7, U2.40 (18_A4_SDA)



Board: 2 copper layers, 60.7 x 105.2 mm, 22 parts (14 on the bottom side), 58 nets.

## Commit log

2023-06-07 tracked WIP
    [12HP_Front_panel.kicad_pcb, Port A.kicad_sch, Port B.kicad_sch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]
2023-06-07 laid out
    [usb_midi_clocker circuits.kicad_pcb, usb_midi_clocker circuits.kicad_sch]
2023-06-08 laid out some more
    [usb_midi_clocker circuits.kicad_pcb, usb_midi_clocker circuits.kicad_sch]
2023-06-09 rough layout of single midi expander
    [expander_midi.kicad_pcb, expander_midi.kicad_sch]
2023-06-09 further tweaks
    [expander_midi.kicad_pcb]
2023-06-10 cleaned up schematic a little to add the front/backboard connection
    [expander_midi.kicad_pcb, expander_midi.kicad_sch]
2023-06-10 laid out quite nicely now i think
    [expander_midi.kicad_pcb, expander_midi.kicad_sch]
2023-06-10 put output jacks in correct order, added labelling to pins
    [expander_midi.kicad_pcb]
2023-06-10 screenies + jlcpcb placeholders
    [expander_midi.kicad_pcb]
2023-06-13 updated files
    [bom.csv, designators.csv, expander_cv_input.kicad_pcb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]
2023-06-20 before changing midi footprints
    [Port A.kicad_sch, Port B.kicad_sch, bom.csv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]
2023-06-21 sent to jlcpcb
    [bom.csv, designators.csv, expander_midi.kicad_pcb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]
2023-06-22 tracked zips
    [bom.csv, designators.csv, positions.csv]
2023-10-21 solve a couple of problems on main board + main panel
    [bom.csv, designators.csv, expander_usb_sd.kicad_pcb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]
2023-10-26 fix user drawing line on wrong layer (user1, interpreted as vcut!!) causing rejection by jlcpcb!!
    [usb_midi_clocker circuits.kicad_pcb]
2023-10-26 fixed gerbers
2023-12-30 most of USB+SD card expander done
    [expander_usb_sd.kicad_pcb, expander_usb_sd.kicad_sch]
2023-12-30 improved schematic layout a little
    [expander_gate_output.kicad_sch]
2024-01-13 updated to correct(?) footprint + 3d model for the usb socket
    [expander_usb_sd.kicad_pcb, expander_usb_sd.kicad_sch]
2024-01-13 update labling
    [expander_usb_sd.kicad_pcb, expander_usb_sd.kicad_sch]
2024-02-10 fucking connect the USB Host pins that were completely unconnected previously... facepalm!
    [expander_usb_sd.kicad_pcb, expander_usb_sd.kicad_sch]
2024-02-10 flip headers back to correct side of board
    [expander_usb_sd.kicad_pcb]
2024-02-11 some improved routing
    [expander_usb_sd.kicad_pcb]
2024-07-02 fixed yet more dumb routing errors on the usb_sd; probably still isn't ready to use
    [expander_usb_sd.kicad_pcb, expander_usb_sd.kicad_sch]
2024-07-14 believe fixed problems with expander_usb_sd; tracked a bunch of stuff that was untracked (expander_cv_output?)
    [bom.csv, dac1.kicad_sch, dac2.kicad_sch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]
2024-08-18 swap accidentally flipped resistors on outputs 13+14
    [expander_gate_output.kicad_pcb]
2024-08-18 moved track to eliminate a DRC error
    [expander_gate_output.kicad_pcb]
2024-12-29 tracked first draft of expander_cv_output
    [bom.csv, cv_input.kicad_sch, dac1.kicad_sch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]
2024-12-29 fixed incorrectly reversed analog input pins *facepalm*
    [cv_input.kicad_sch, expander_cv_output.kicad_pcb]
2024-12-31 removed some redundant traces
    [expander_cv_output.kicad_pcb]
